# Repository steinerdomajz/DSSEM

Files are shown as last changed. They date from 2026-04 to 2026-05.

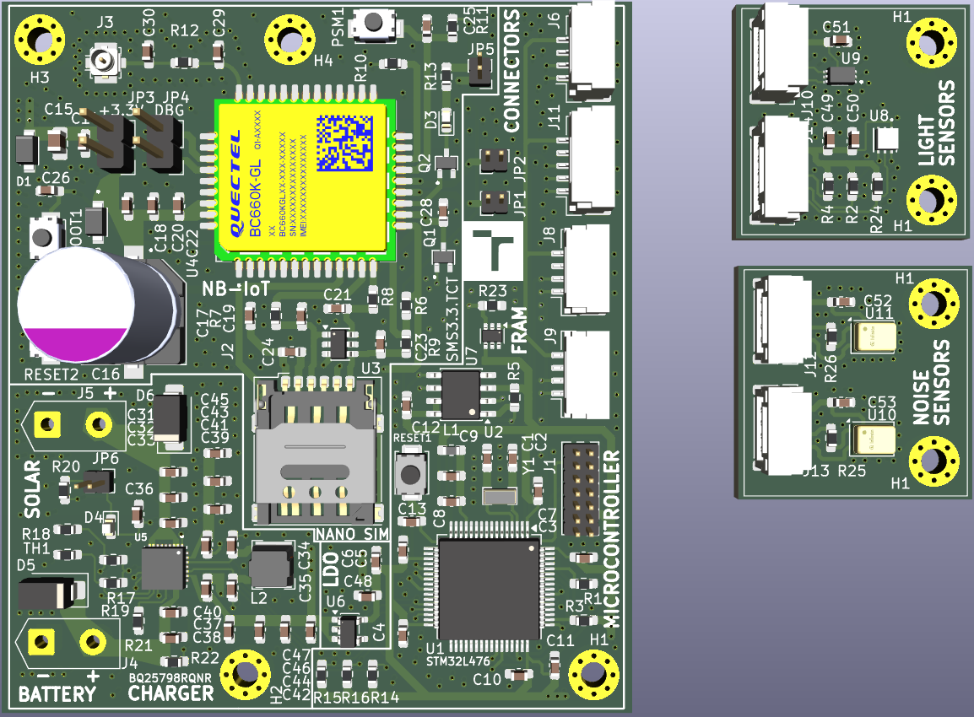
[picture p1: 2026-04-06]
hardware/PCB_front_v02_edit.png

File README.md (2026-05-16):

# System for Environmental Monitoring in Protected Areas
**Master's Thesis Project** | Brno University of Technology (FEKT VUT)

This repository contains a demonstration of my final thesis project: an autonomous IoT system designed for long-term monitoring of acoustic and light pollution in sensitive environments.

Presentation available: DSSEM_presentation.pdf

**Key Features**:
- **Autonomous Operation**: Powered by a solar energy harvesting system.
- **Low-Power Design**: Optimized for long-term deployment in remote areas with minimal maintenance.
- **Connectivity**: Real-time data transmission via NB-IoT.
- **Sensor Precision**: Integrated high-sensitivity sensors for measuring environmental noise and light levels.

**Tech Stack**:
- **Electronics**: Custom PCB designed in KiCad.
- **Firmware**: Developed for MCU to handle sensor data and communication protocols.
- **Mechanical Design**: Protective environmental casing designed in SolidWorks.

--- **Hardware Design & Implementation:** ---

PCB_front_v02_edit

--- **Firmware:** ---






--- **Mechanical Design:** ---





--- **Implementation:** ---

Node-RED Flowchart:



InfluxDB Visualisation:



User Configuration Site (Web Serial API):



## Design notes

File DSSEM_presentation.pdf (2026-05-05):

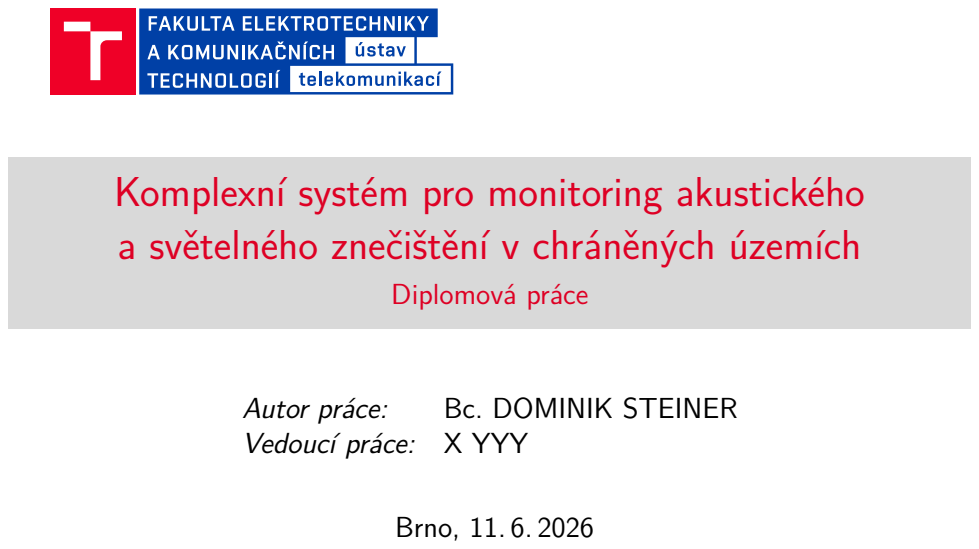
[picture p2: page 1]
Diplomová práce; Autor práce:; Bc. DOMINIK STEINER; Brno, 11. 6. 2026

Komplexní systém pro monitoring akustického
a světelného znečištění v chráněných územích

Vedoucí práce: X YYY

# Cíl práce

# Návrh a realizace systému pro dlouhodobý monitoring akustického a světelného znečištění

# Přenos dat pomocí NB-IoT Energeticky soběstačné řešení založeno na solárním napájení Systém pro bezpečný přenos dat Ukládání dat do databázového systému a následná vizualizace

# Výstupem práce bude funkční prototyp

Bc. Dominik Steiner | Komplexní systém pro monitoring akustického a světelného znečištění v chráněných územích | 1 / 13

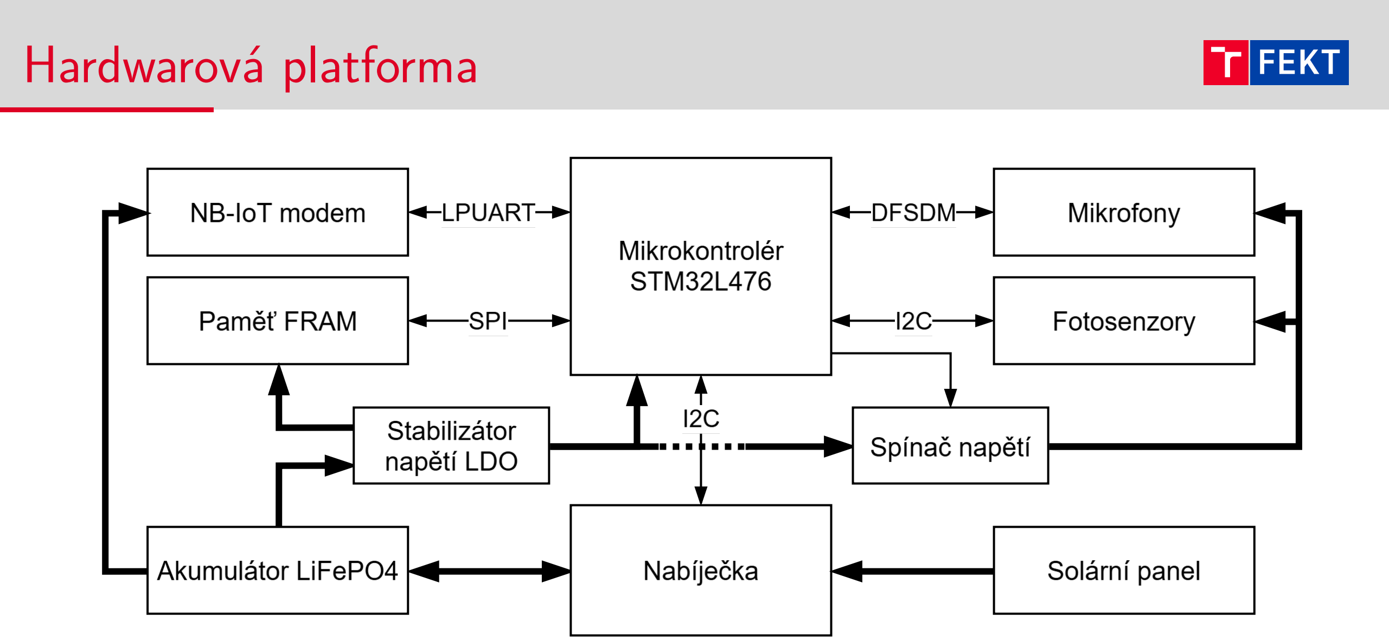
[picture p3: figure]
Hardwarová platforma

# Obr. 1: Blokový diagram HW platformy

Bc. Dominik Steiner | Komplexní systém pro monitoring akustického a světelného znečištění v chráněných územích | 2 / 13

# Hardwarová platforma

# Mikrokontrolér STM32L476

# Ultra-Low-power řada

# NB-IoT modul BC660K-GL

# Nabíječka BQ25798

# LiFePO4 akumulátor

# FRAM MB85RS2MTA

# MEMS mikrofony

# Fotosenzory

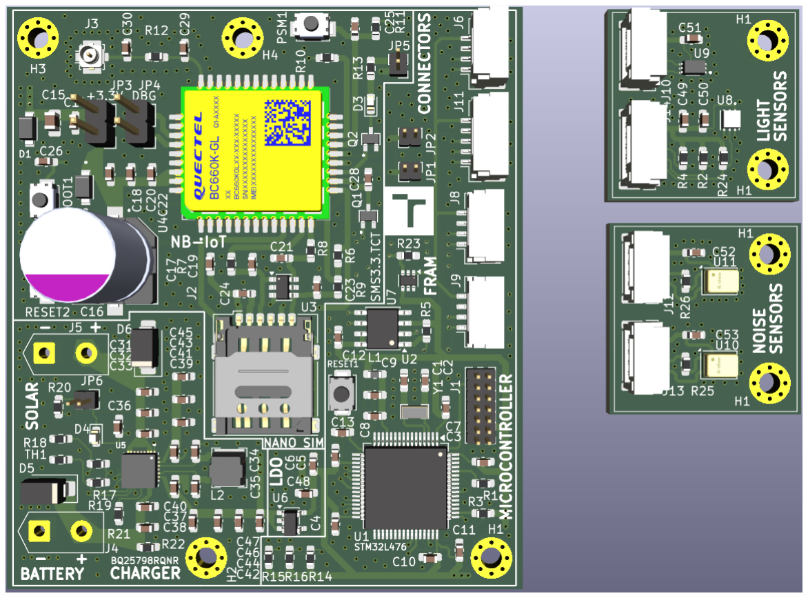
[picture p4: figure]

# Obr. 2: Návrh DPS

Bc. Dominik Steiner | Komplexní systém pro monitoring akustického a světelného znečištění v chráněných územích | 3 / 13

# Firmware

# Senzorové měření

# Měření osvitu Měření hladiny hluku (integrace časového okna)

# Zápis do FRAM

# 16bajtová struktura Až 9375 záznamů Kruhový buffer

# Komunikační blok

# Šifrování AES-128 + CBC

# UDP protokol

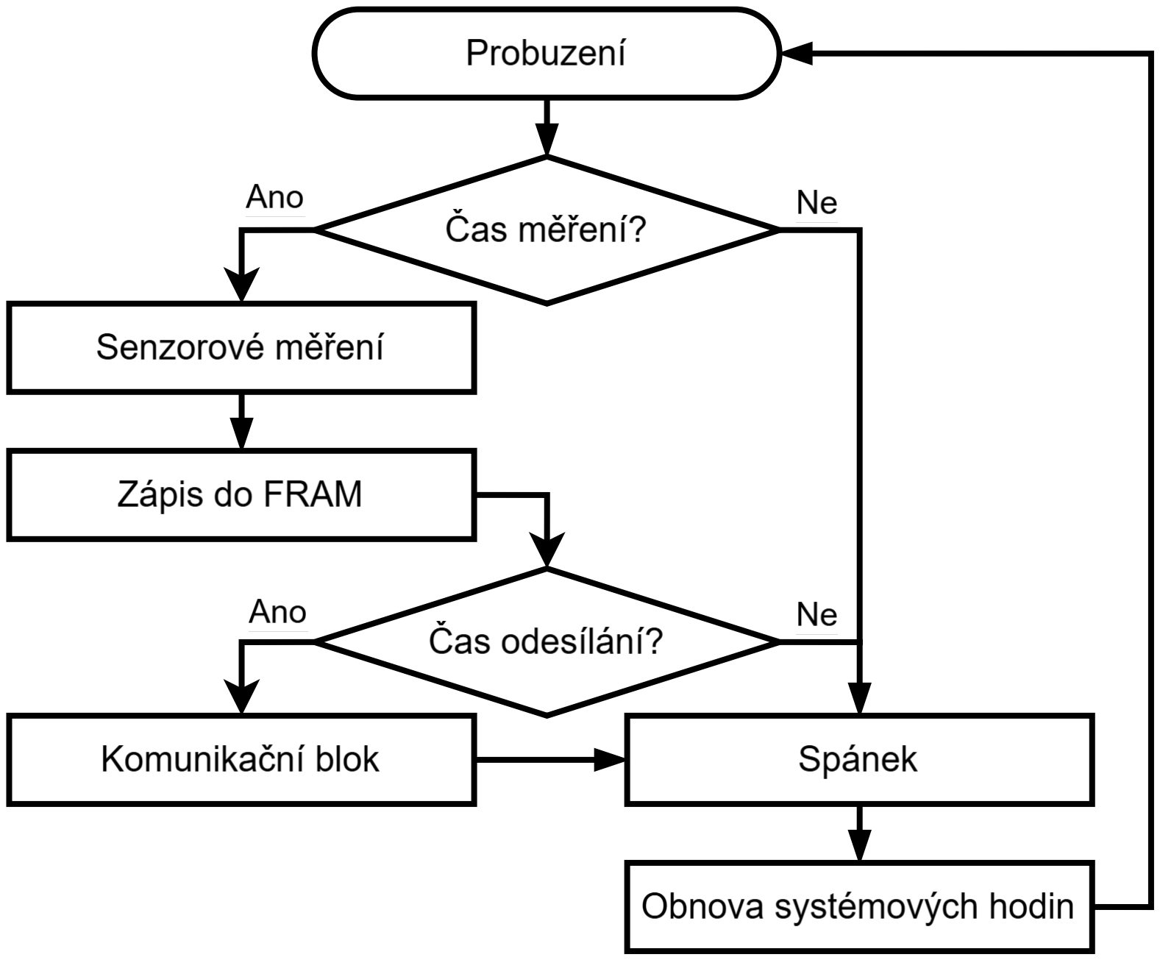
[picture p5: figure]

Spánek | Obr. 3: Zjednodušený diagram hlavního
| cyklu
Bc. Dominik Steiner | Komplexní systém pro monitoring akustického a světelného znečištění v chráněných územích | 4 / 13

# Server

# Stamp Check: Kontrola identifikační značky

# Decryption: Dešifrování dat

# Time Shift: Převod lokálního času na UTC

# Format for InfluxDB: Formátování dat v souladu s InfluxDB

# Obr. 4: Flow chart Node-RED

Bc. Dominik Steiner | Komplexní systém pro monitoring akustického a světelného znečištění v chráněných územích | 5 / 13

# Energetická náročnost zařízení

# Spánek

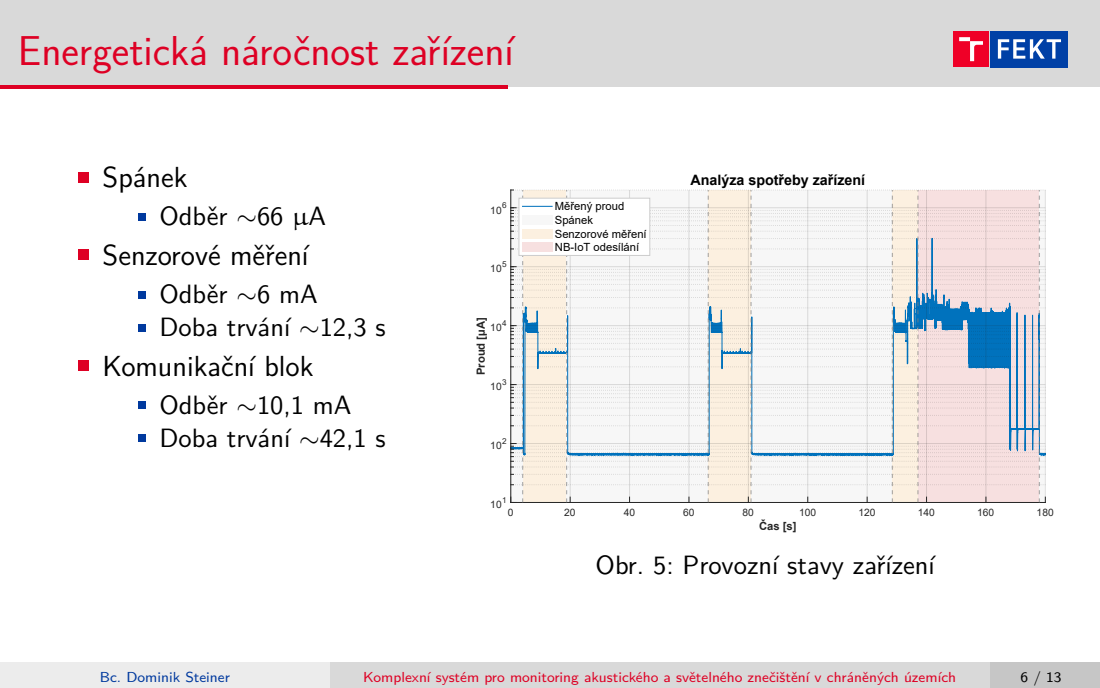
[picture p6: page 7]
Odběr ∼66 µA; Senzorové měření; Odběr ∼6 mA Doba trvání ∼12,3 s; Komunikační blok; Odběr ∼10,1 mA Doba trvání ∼42,1 s; Čas [s]; Proud [µA]; Bc. Dominik Steiner; Komplexní systém pro monitoring akustického a světelného znečištění v chráněných územích

Analýza spotřeby zařízení

Měřený proud
Spánek
Senzorové měření
NB-IoT odesílání

Obr. 5: Provozní stavy zařízení

# Energetická náročnost zařízení

# Připojování do sítě

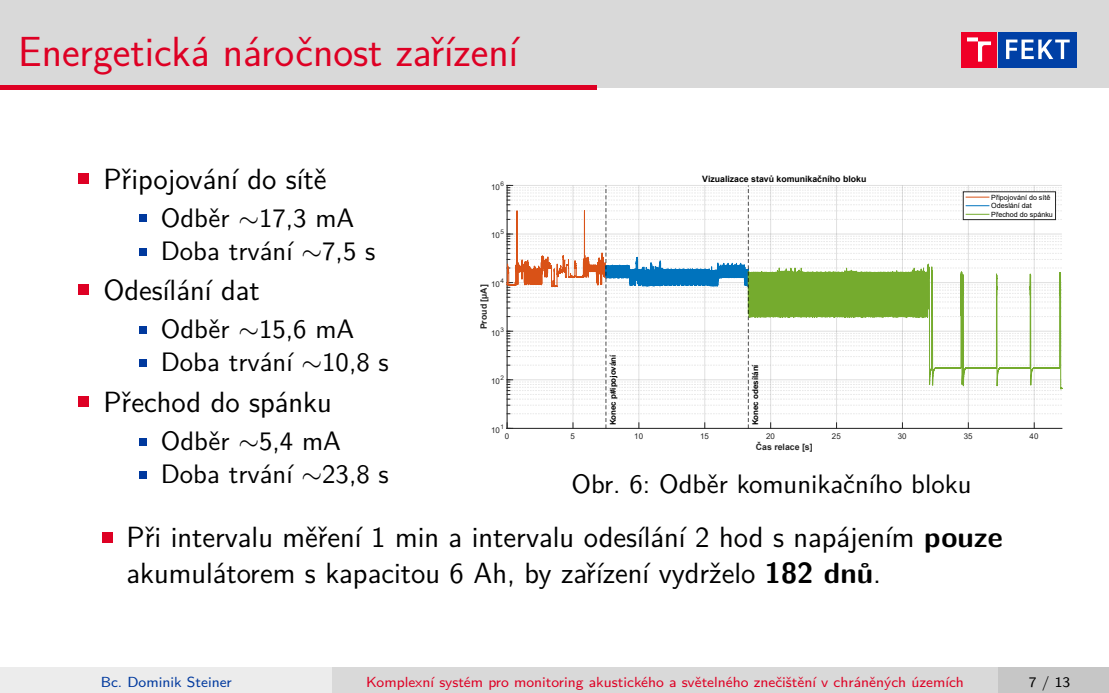
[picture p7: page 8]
Čas relace [s]; Proud [µA]; Konec p#ipojování; Konec odesílání; Bc. Dominik Steiner; Komplexní systém pro monitoring akustického a světelného znečištění v chráněných územích

Vizualizace stavů komunikačního bloku

Připojování do sítě
Odeslání dat
Přechod do spánku

Odběr ∼17,3 mA
Doba trvání ∼7,5 s
Odesílání dat
Odběr ∼15,6 mA
Doba trvání ∼10,8 s
Odběr ∼5,4 mA
Doba trvání ∼23,8 s

Obr. 6: Odběr komunikačního bloku

Při intervalu měření 1 min a intervalu odesílání 2 hod s napájením pouze
akumulátorem s kapacitou 6 Ah, by zařízení vydrželo 182 dnů.

# Mechanické pouzdro

# Základový modul + senzorové moduly

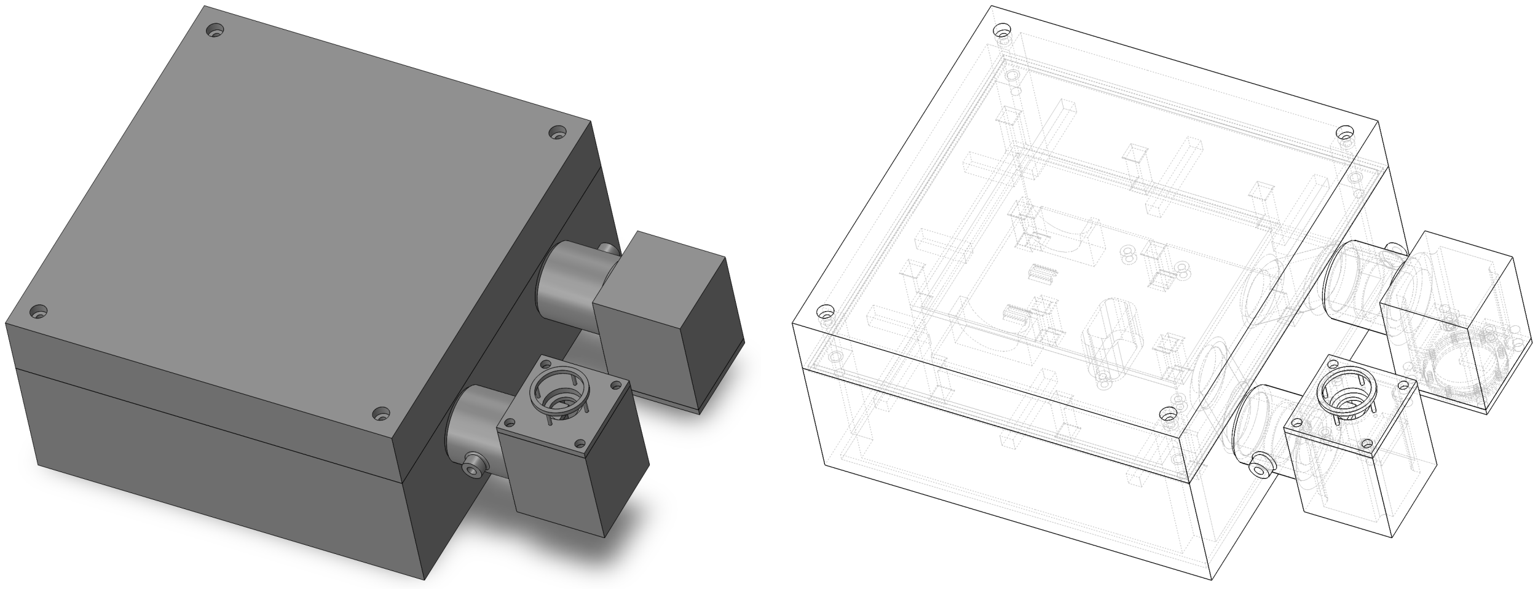
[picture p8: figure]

# Obr. 7: Model mechanického pouzdra zařízení

Bc. Dominik Steiner | Komplexní systém pro monitoring akustického a světelného znečištění v chráněných územích | 8 / 13

# Základový modul

# Komora pro akumulátor a DPS Izolace pomocí pěnového polyuretanu (PUR)

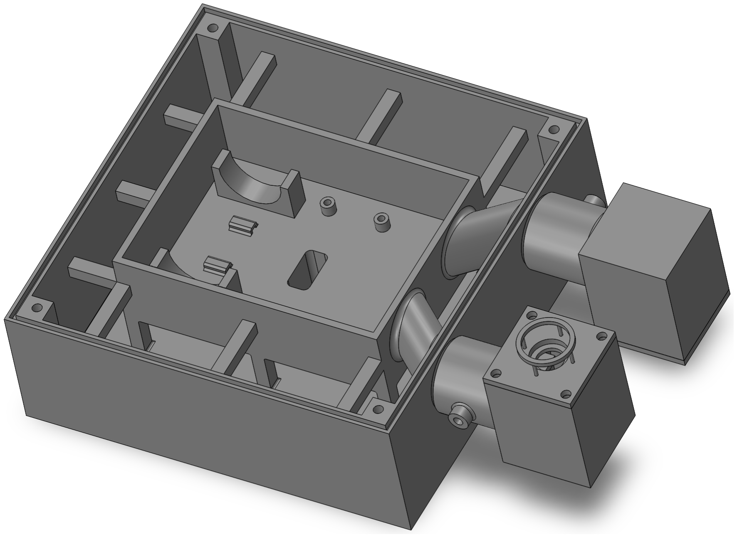
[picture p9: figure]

# Obr. 8: Model základového modulu

Bc. Dominik Steiner | Komplexní systém pro monitoring akustického a světelného znečištění v chráněných územích | 9 / 13

# Senzorové moduly

# Otáčivé moduly pro fotosentory

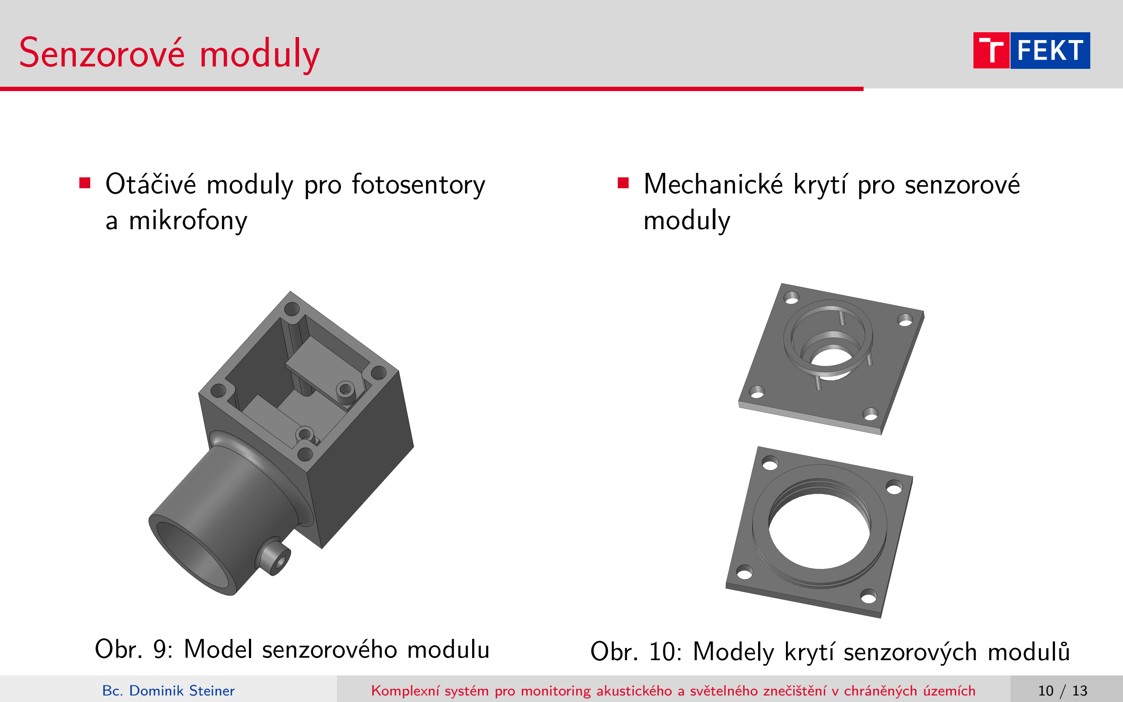
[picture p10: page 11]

# a mikrofony

# Obr. 9: Model senzorového modulu

# Mechanické krytí pro senzorové moduly

# Obr. 10: Modely krytí senzorových modulů

Bc. Dominik Steiner | Komplexní systém pro monitoring akustického a světelného znečištění v chráněných územích | 10 / 13

# Program DSSEM User Configuration

# Jednoduchá uživatelské aplikace pro nastavení:

# Serveru Identifikační značky Intervalu měření a odesílání

# Připojení se zařízením skrze Web Serial API (USB-TTL + UART)

# Výpočet odhadované životnosti zařízení

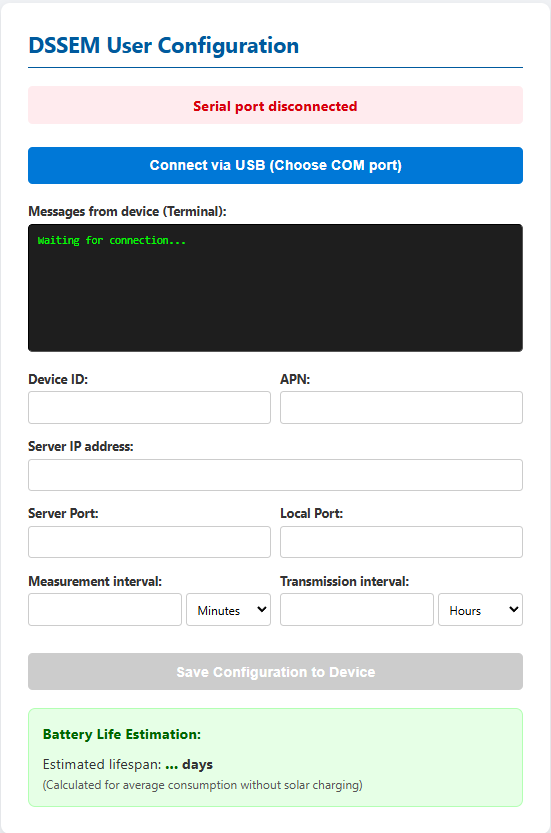
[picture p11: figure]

# Obr. 11: Program User Configuration

Bc. Dominik Steiner | Komplexní systém pro monitoring akustického a světelného znečištění v chráněných územích | 11 / 13

# Závěr

# Realizace návrhu HW platformy

# Měření osvitu a akustického hluku Přenos dat pomocí NB-IoT

# Realizace FW zařízení

# Implementováno šifrování a kruhový buffer pro ukládání dat Ověřena funkční komunikace se vzdáleným serverem Dosažení odběru 66 µA ve spánku

# Mechanické pouzdro

# Vytvořeny modely mechanického pouzdra

# Potřebné kroky pro finalizaci projektu

# 1. Mechanické pouzdro a textová část DP: 2. Program DSSEM User Configuration

Bc. Dominik Steiner | Komplexní systém pro monitoring akustického a světelného znečištění v chráněných územích | 12 / 13

# Děkuji za pozornost!

Bc. Dominik Steiner | Komplexní systém pro monitoring akustického a světelného znečištění v chráněných územích | 13 / 13

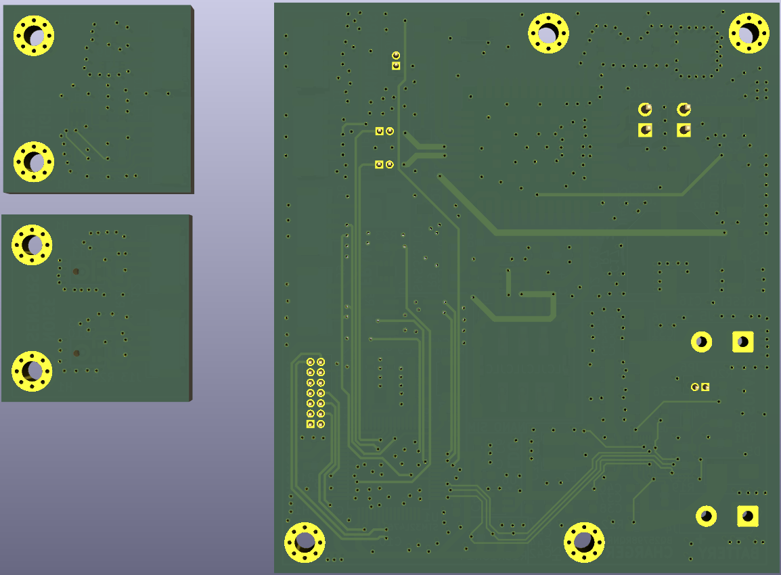
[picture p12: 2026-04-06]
hardware/PCB_back_v02_edit.png

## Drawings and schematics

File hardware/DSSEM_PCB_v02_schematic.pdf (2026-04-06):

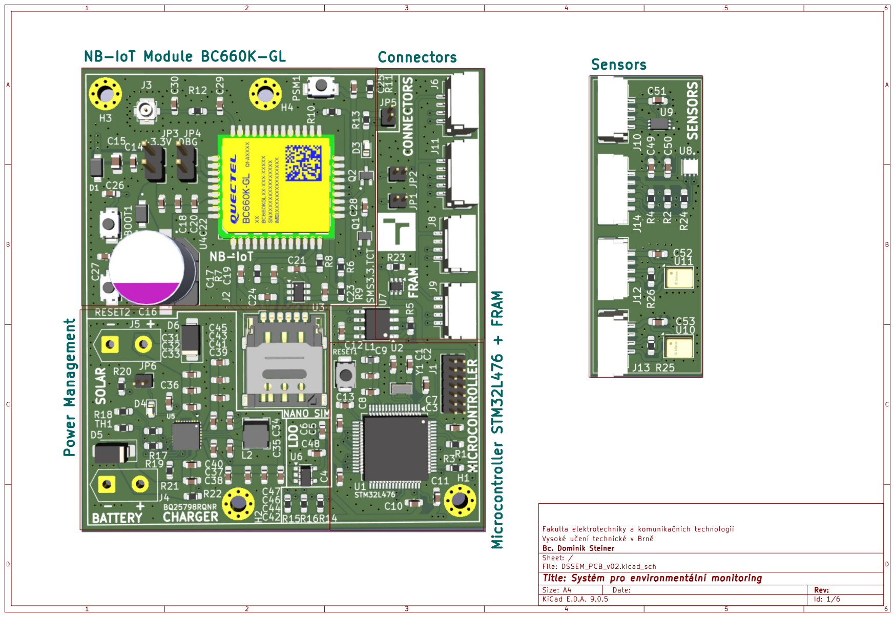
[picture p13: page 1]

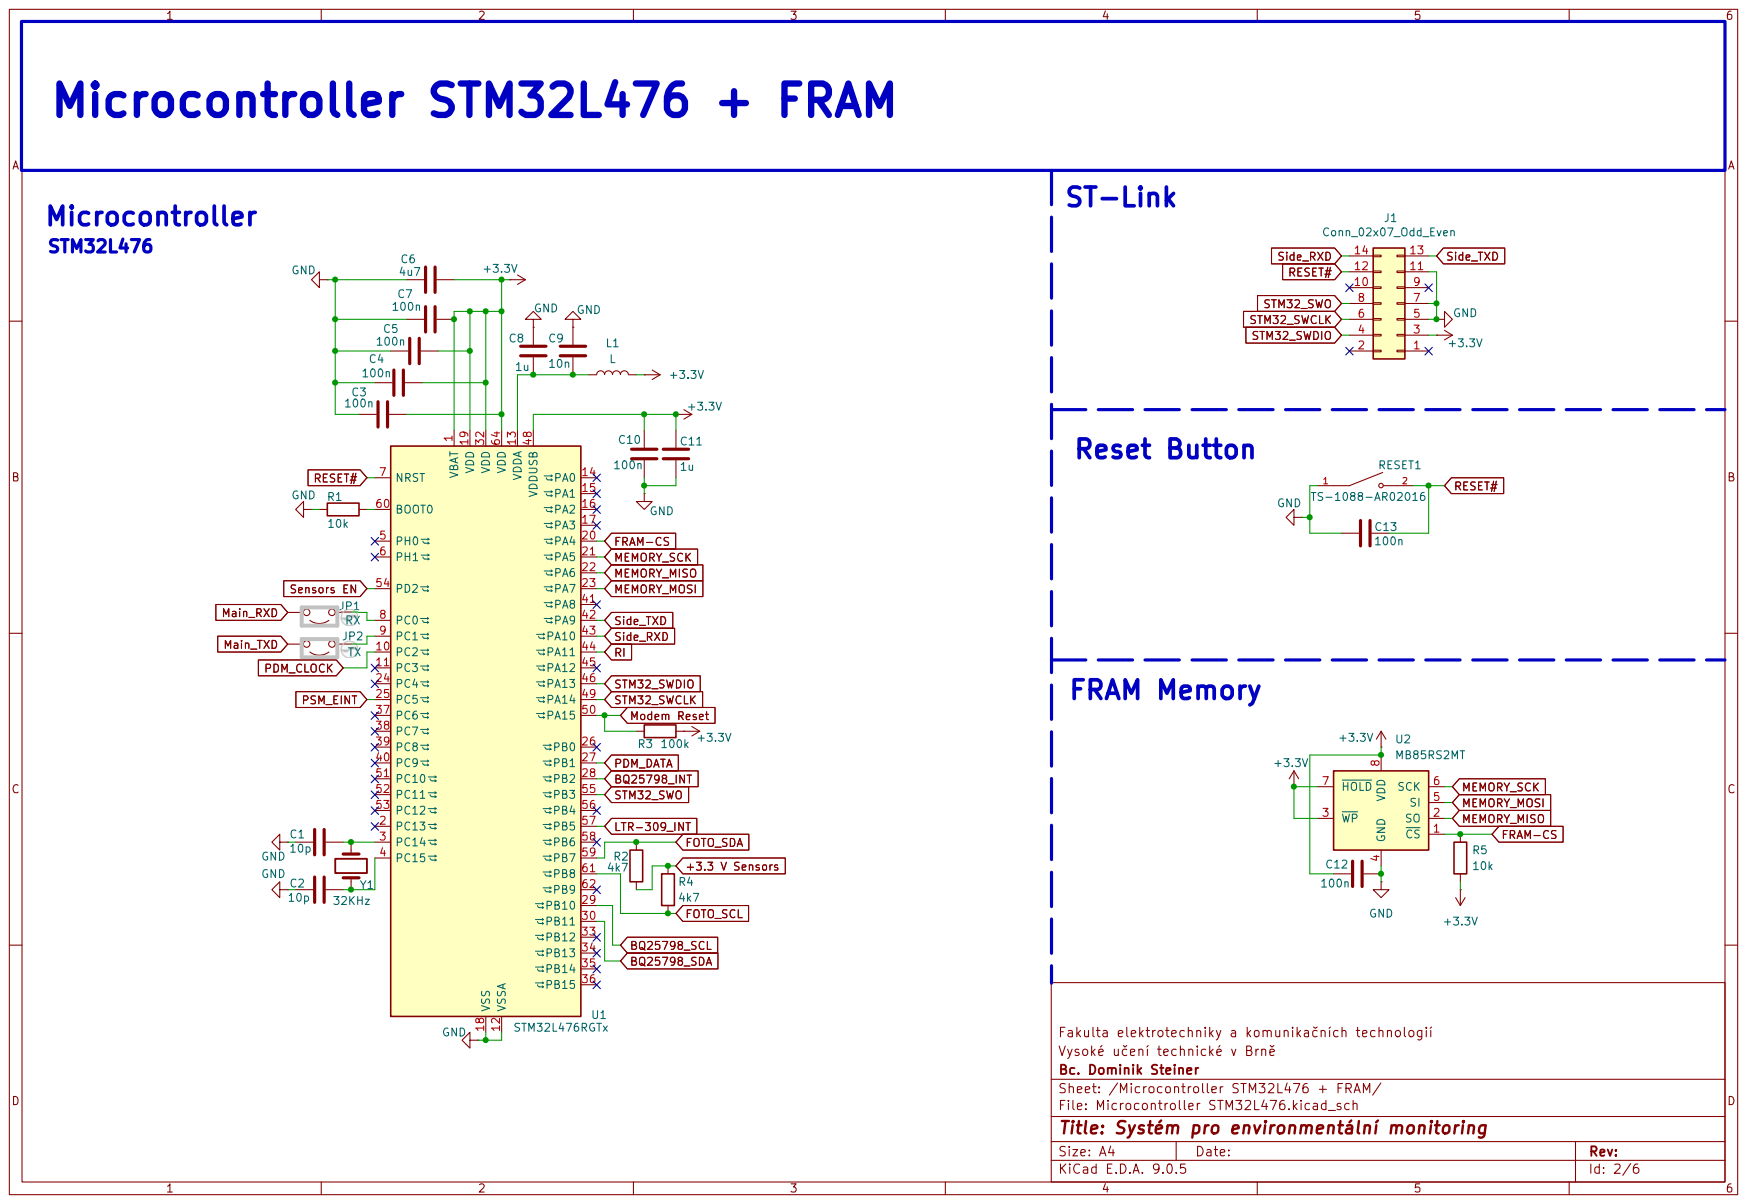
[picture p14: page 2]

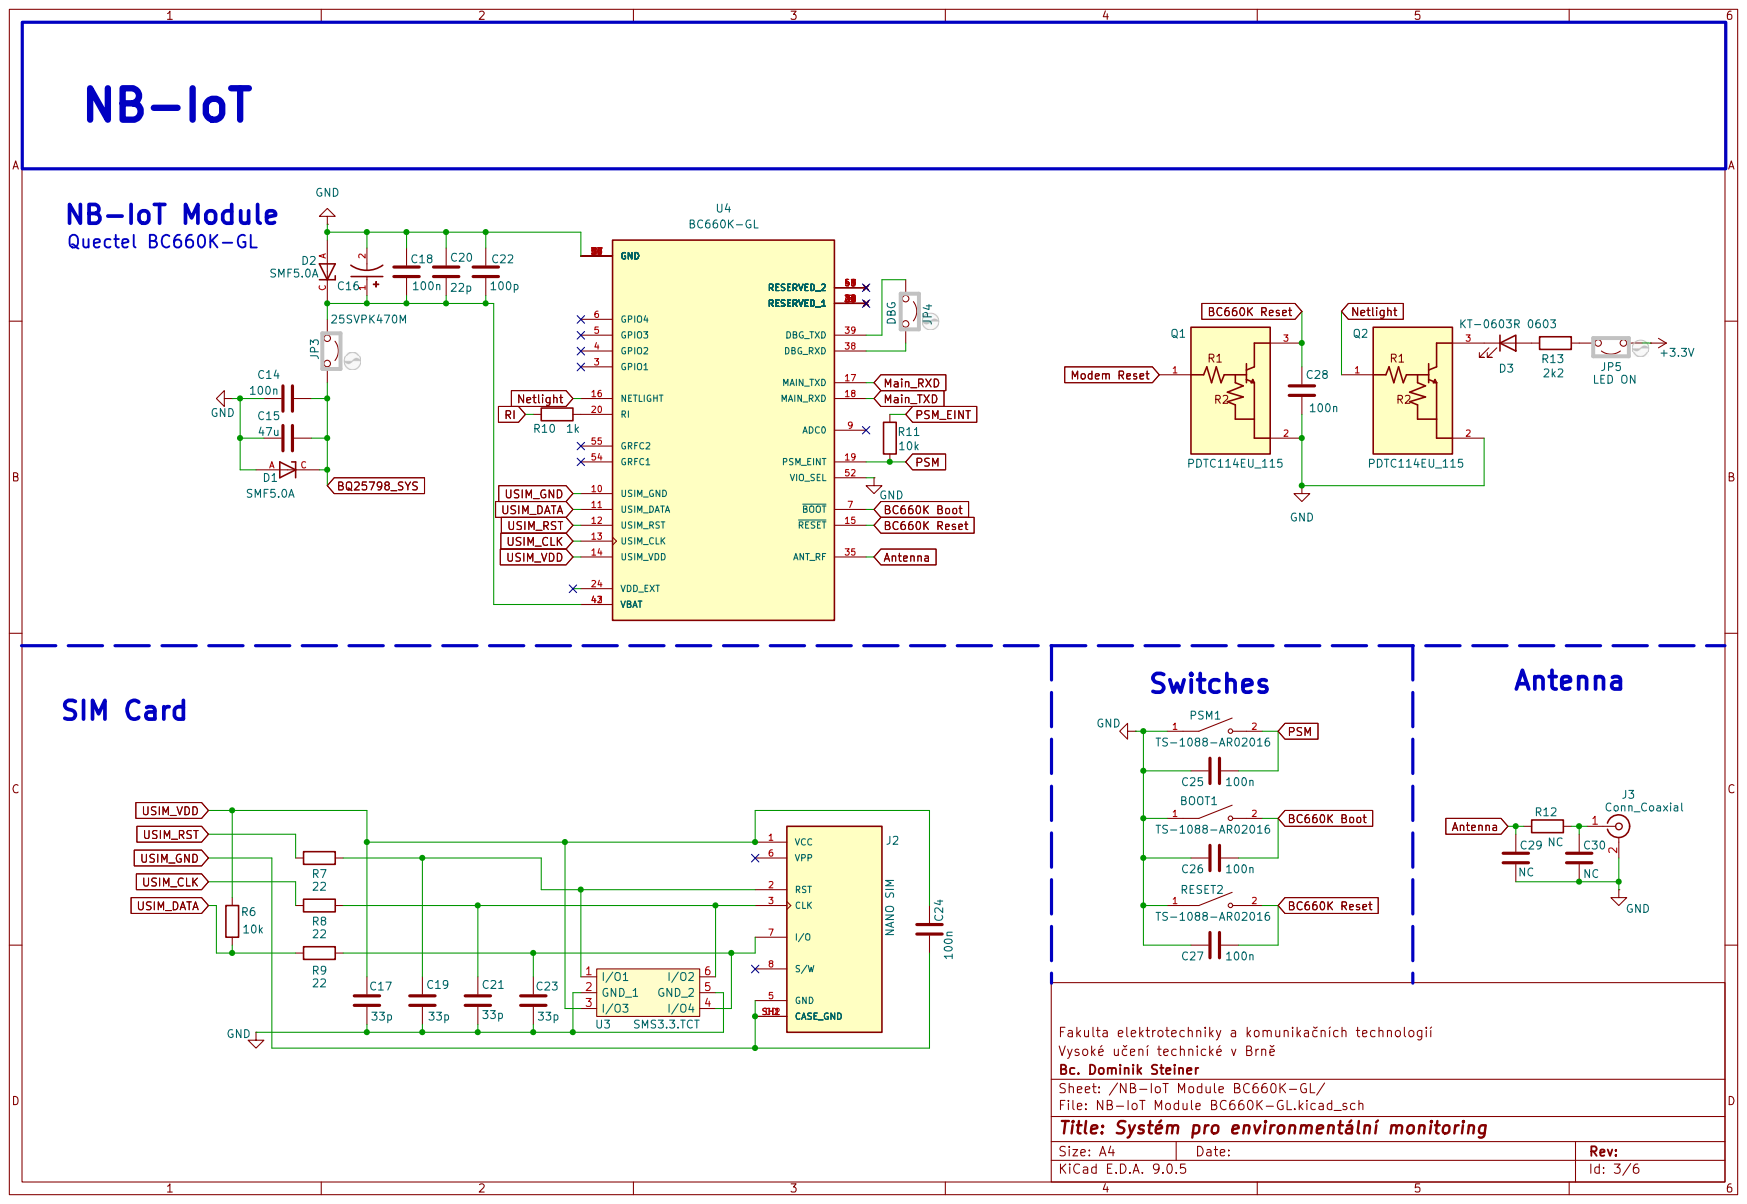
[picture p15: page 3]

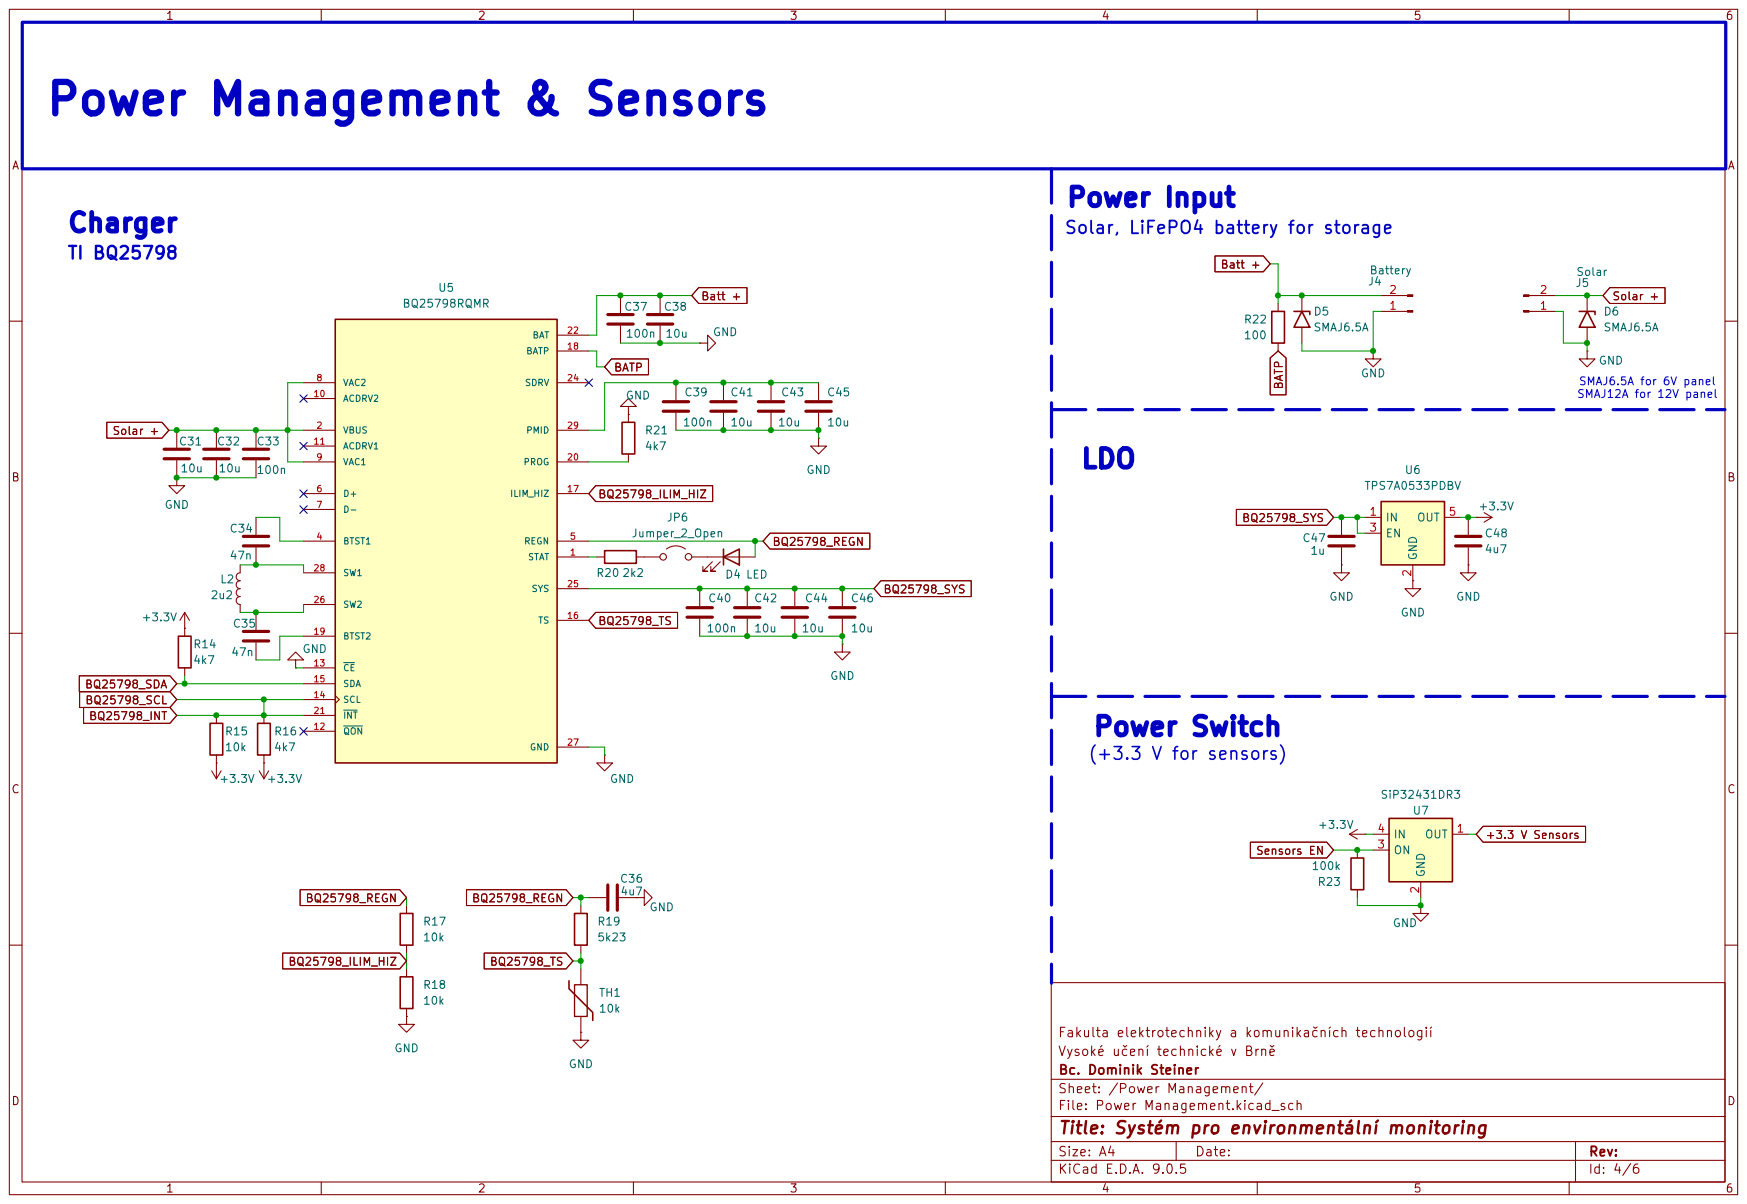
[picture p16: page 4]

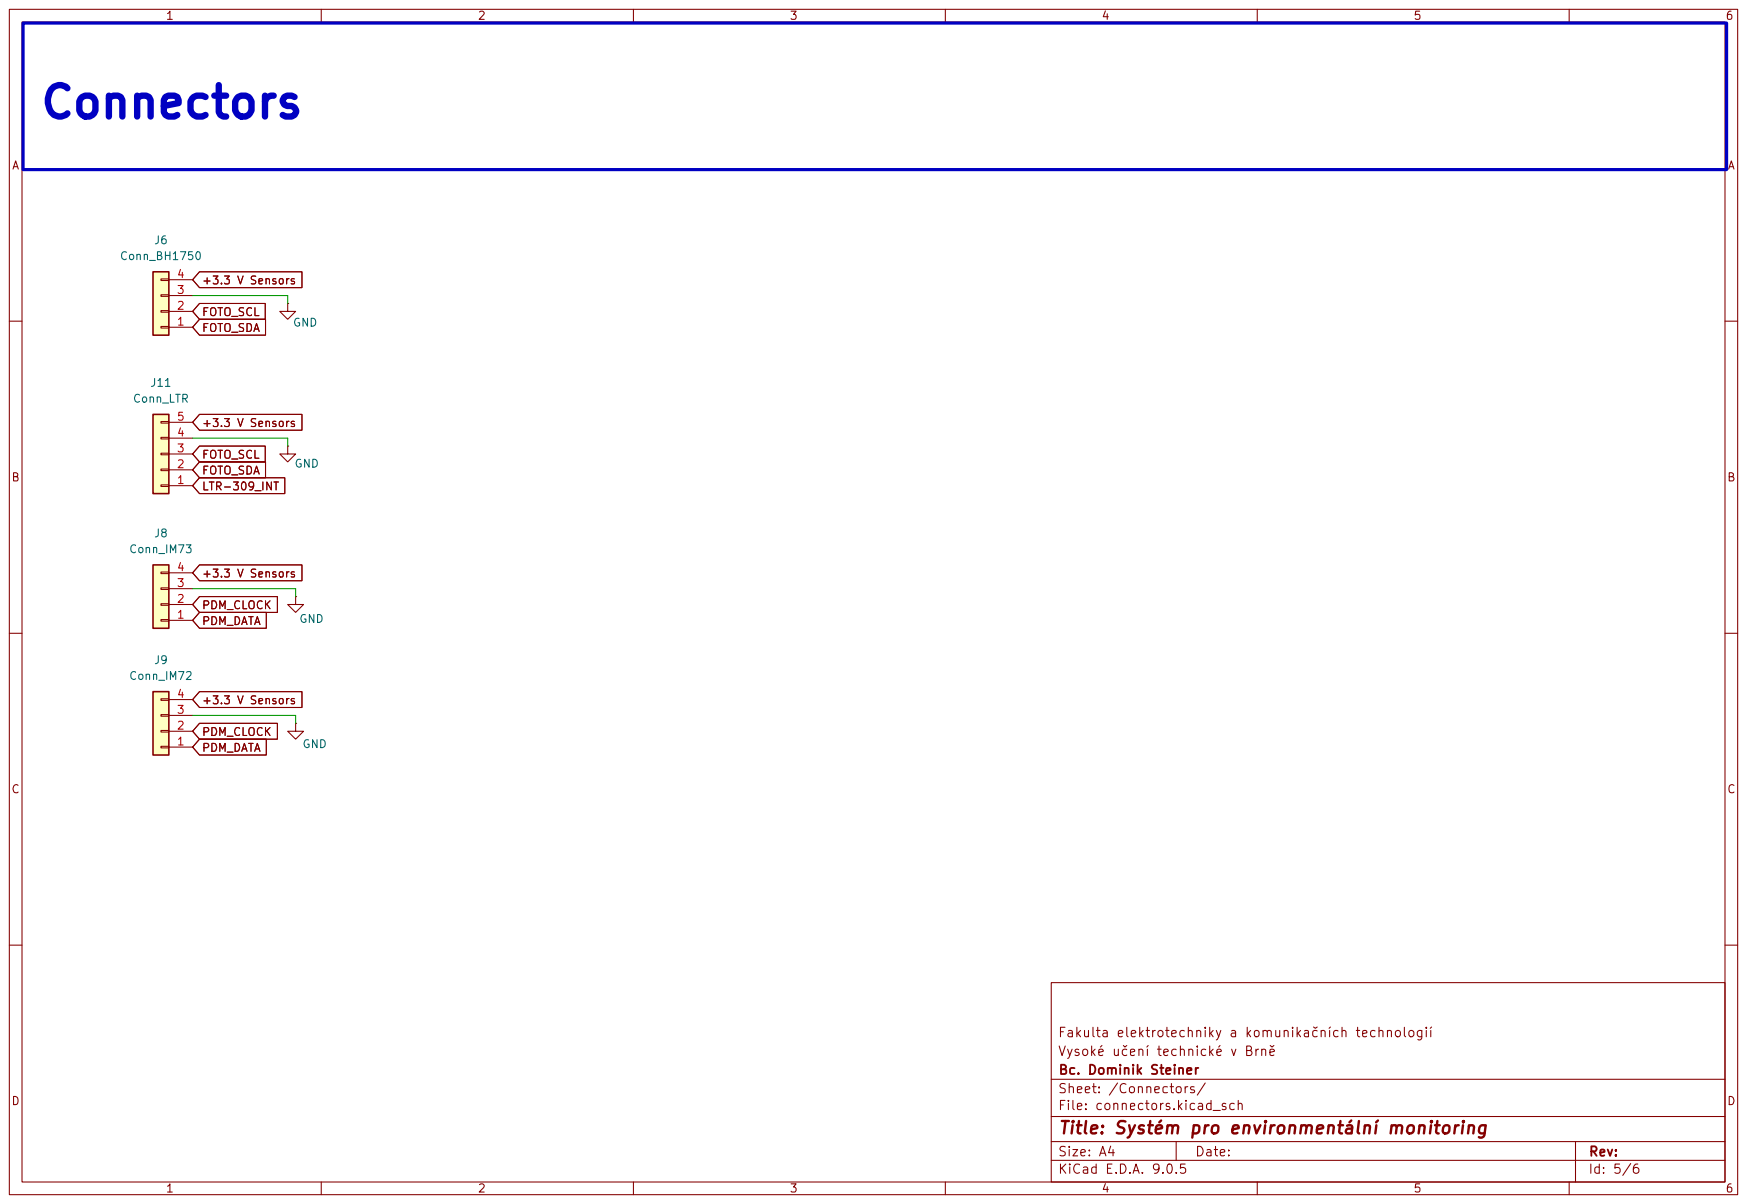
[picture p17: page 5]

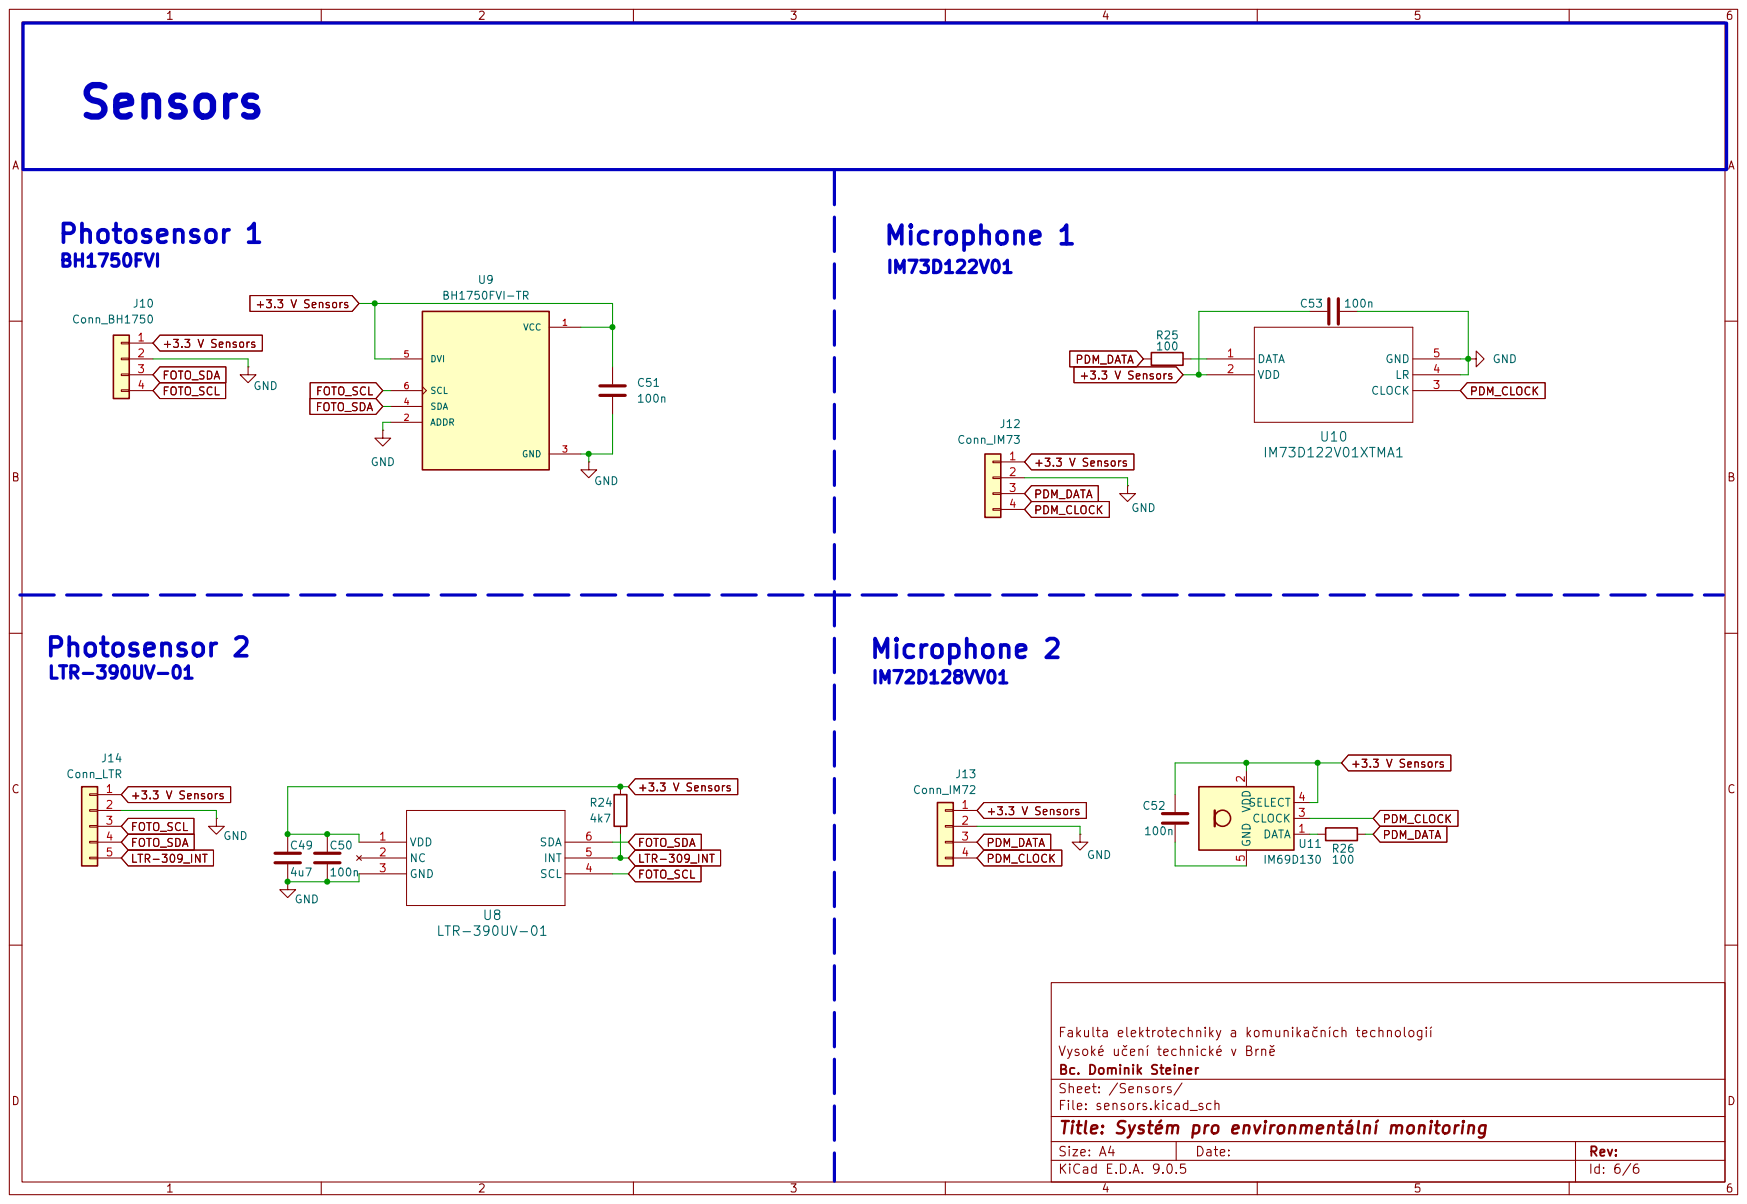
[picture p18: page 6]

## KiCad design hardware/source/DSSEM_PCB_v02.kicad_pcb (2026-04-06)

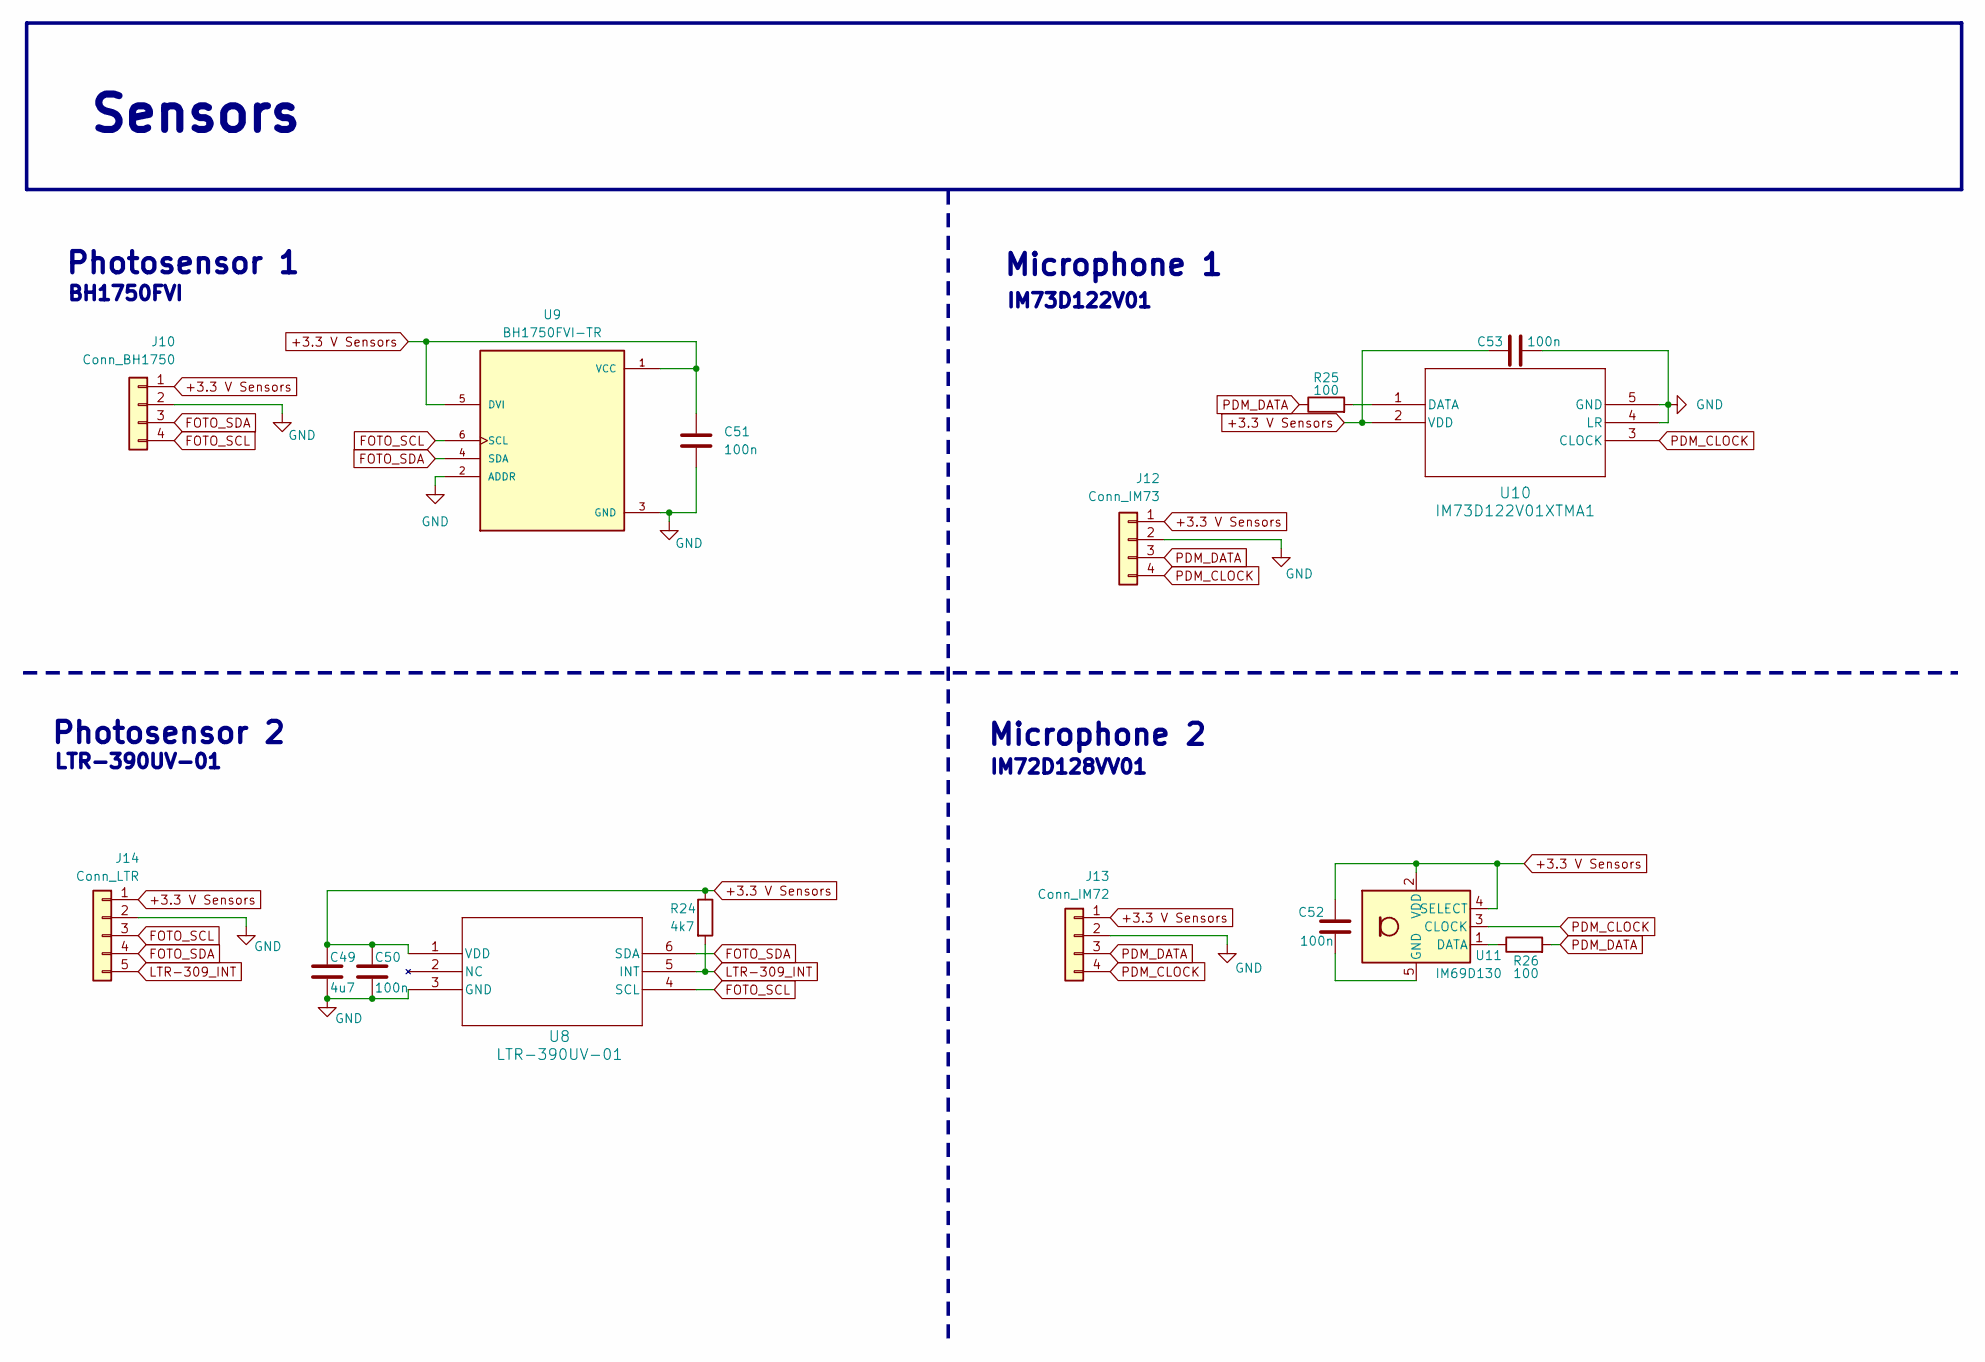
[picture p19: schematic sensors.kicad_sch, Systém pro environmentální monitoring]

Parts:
C49: 4u7; C_0603_1608Metric_Pad1.08x0.95mm_HandSolder
C50, C51, C52, C53: 100n; C_0603_1608Metric_Pad1.08x0.95mm_HandSolder
J10: Conn_BH1750; JST_GH_SM04B-GHS-TB_1x04-1MP_P1.25mm_Horizontal
J12: Conn_IM73; JST_GH_SM04B-GHS-TB_1x04-1MP_P1.25mm_Horizontal
J13: Conn_IM72; JST_GH_SM04B-GHS-TB_1x04-1MP_P1.25mm_Horizontal
J14: Conn_LTR; JST_GH_SM05B-GHS-TB_1x05-1MP_P1.25mm_Horizontal
R24: 4k7; R_0603_1608Metric_Pad0.98x0.95mm_HandSolder
R25, R26: 100; R_0603_1608Metric_Pad0.98x0.95mm_HandSolder
U8: LTR-390UV-01; SMD6_LTR-390UV-01_LTO
U9: BH1750FVI-TR; XDCR_BH1750FVI-TR; PARTREV D
U10: IM73D122V01XTMA1; Infineon_PG-LLGA-5-2
U11: IM69D130; Infineon_PG-LLGA-5-1

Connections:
+3.3 V Sensors: C49.1, C50.1, C51.1, C52.1, C53.1, J10.1, J12.1, J13.1, J14.1, R24.1, U8.1 (VDD), U9.1 (VCC), U9.5 (DVI), U10.2 (VDD), U11.2 (VDD), U11.4 (SELECT); also elsewhere on the board
FOTO_SCL: J10.4, J14.3, U8.4 (SCL), U9.6 (SCL); also elsewhere on the board
FOTO_SDA: J10.3, J14.4, U8.6 (SDA), U9.4 (SDA); also elsewhere on the board
GND: C49.2, C50.2, C51.2, C53.2, J10.2, J12.2, J13.2, J14.2, U8.3 (GND), U9.2 (ADDR), U9.3 (GND), U10.4 (LR), U10.5 (GND); also elsewhere on the board
LTR-309_INT: J14.5, R24.2, U8.5 (INT); also elsewhere on the board
unnamed: R25.2, U10.1 (DATA)
unnamed: R26.1, U11.1 (DATA)
unnamed: C52.2, U11.5 (GND)
PDM_CLOCK: J12.4, J13.4, U10.3 (CLOCK), U11.3 (CLOCK); also elsewhere on the board
PDM_DATA: J12.3, J13.3, R25.1, R26.2; also elsewhere on the board

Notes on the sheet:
Microphone 2
BH1750FVI
Photosensor 1
LTR-390UV-01
IM73D122V01
IM72D128VV01
Photosensor 2
Sensors
Microphone 1

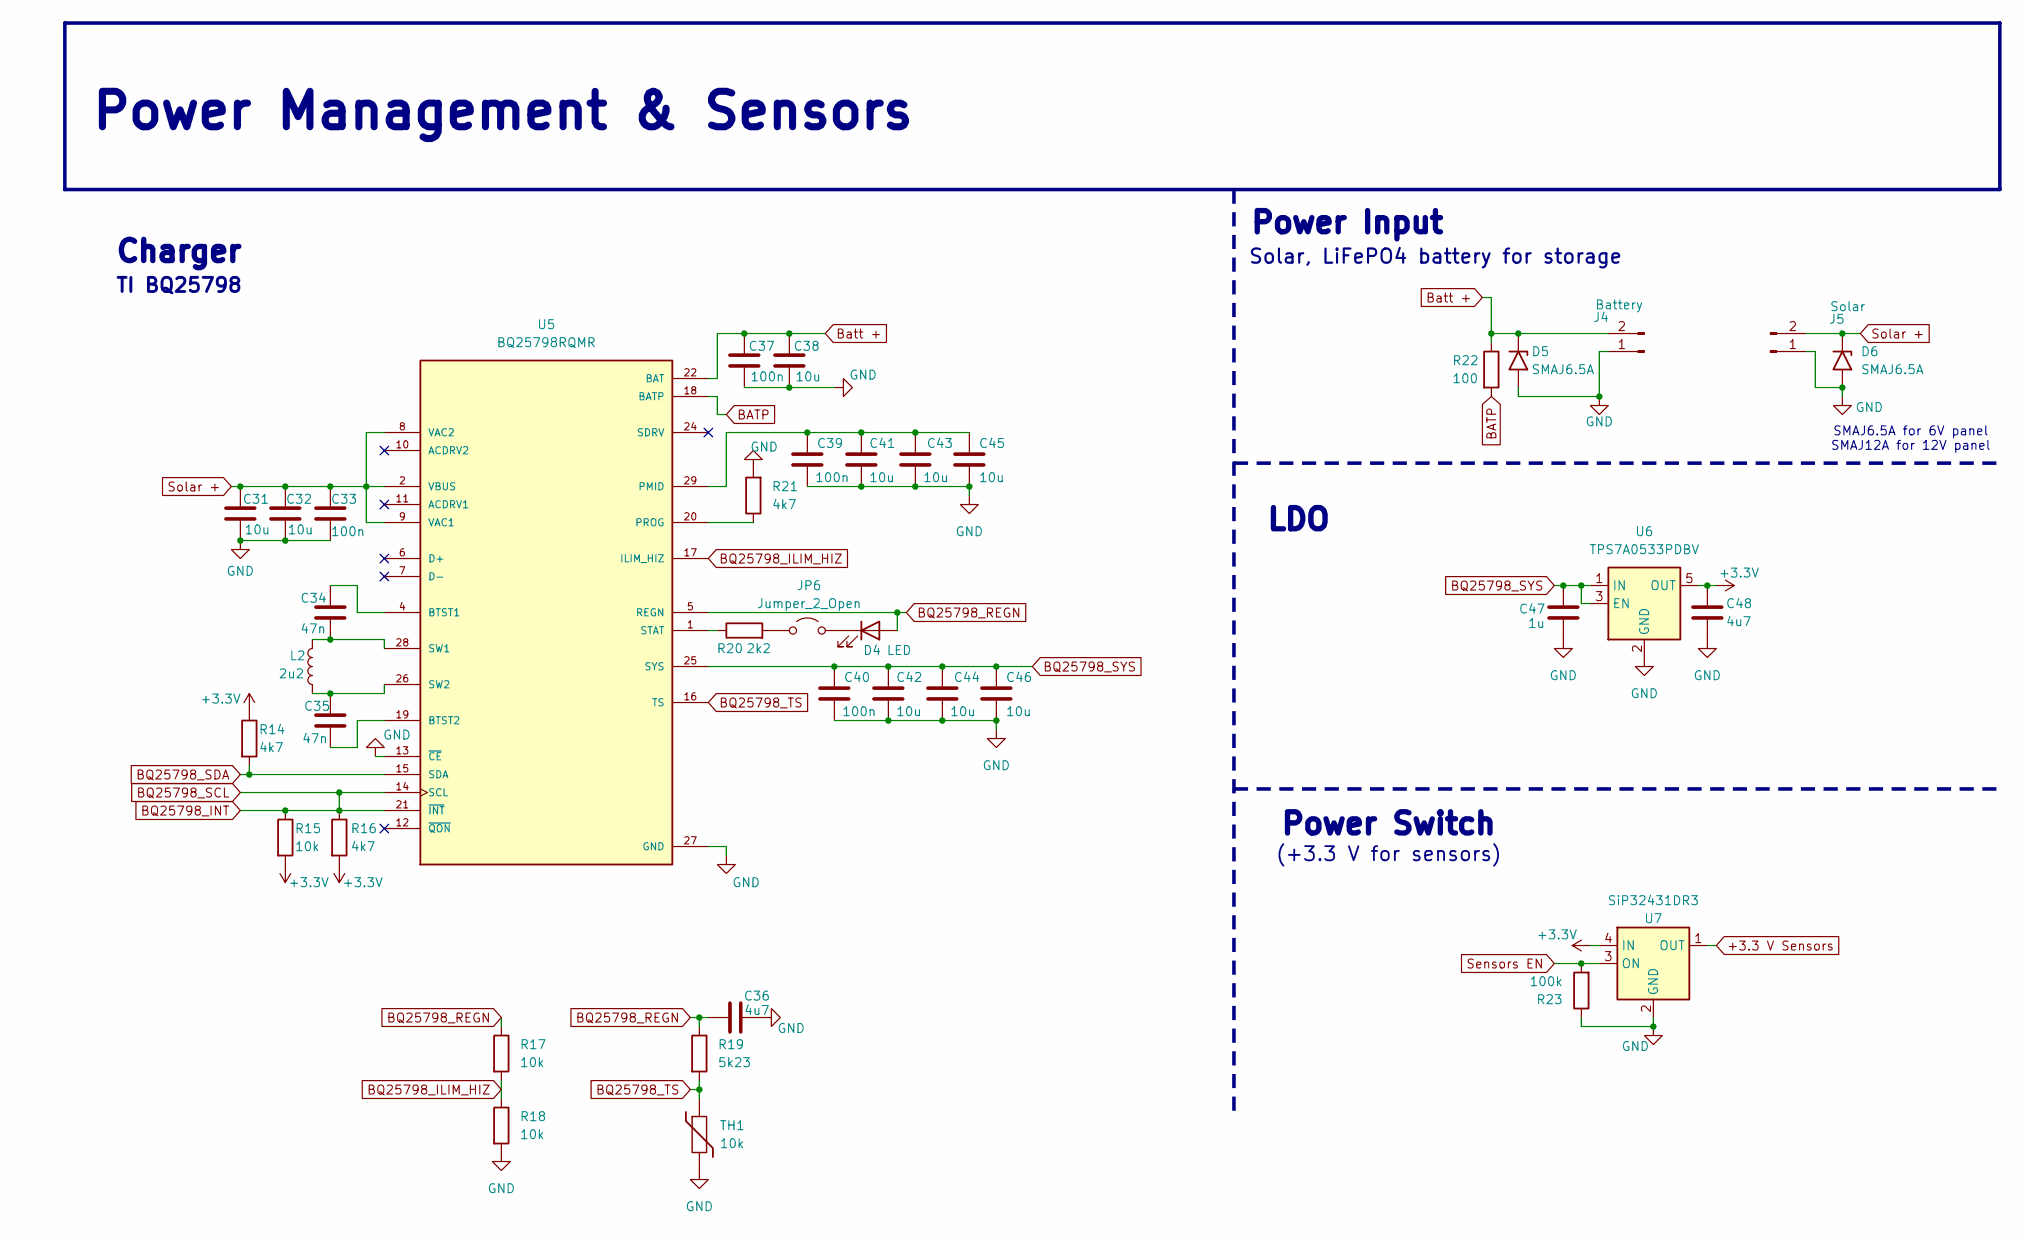
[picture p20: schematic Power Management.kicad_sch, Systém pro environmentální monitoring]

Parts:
C31, C32, C38, C41, C42, C43, C44, C45, C46: 10u; C_0603_1608Metric_Pad1.08x0.95mm_HandSolder
C33, C37, C39, C40: 100n; C_0603_1608Metric_Pad1.08x0.95mm_HandSolder
C34, C35: 47n; C_0603_1608Metric_Pad1.08x0.95mm_HandSolder
C36, C48: 4u7; C_0603_1608Metric_Pad1.08x0.95mm_HandSolder
C47: 1u; C_0603_1608Metric_Pad1.08x0.95mm_HandSolder
D4: LED; LED_0603_1608Metric
D5, D6: SMAJ6.5A; D_SMA
J4: Battery; TerminalBlock_Phoenix_MKDS-1,5-2-5.08_1x02_P5.08mm_Horizont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
J5: Solar; TerminalBlock_Phoenix_MKDS-1,5-2-5.08_1x02_P5.08mm_Horizont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
JP6: Jumper_2_Open; PinHeader_1x02_P1.27mm_Vertical
L2: 2u2; L_Bourns-SRN4018
R14, R16, R21: 4k7; R_0603_1608Metric_Pad0.98x0.95mm_HandSolder
R15, R17, R18: 10k; R_0603_1608Metric_Pad0.98x0.95mm_HandSolder
R19: 5k23; R_0603_1608Metric_Pad0.98x0.95mm_HandSolder
R20: 2k2; R_0603_1608Metric_Pad0.98x0.95mm_HandSolder
R22: 100; R_0603_1608Metric_Pad0.98x0.95mm_HandSolder
R23: 100k; R_0603_1608Metric_Pad0.98x0.95mm_HandSolder
TH1: 10k; R_0603_1608Metric_Pad0.98x0.95mm_HandSolder
U5: BQ25798RQMR; IC_BQ25798RQMR; PARTREV B
U6: TPS7A0533PDBV; SOT-23-5
U7: SiP32431DR3; SOT-363_SC-70-6

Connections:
+3.3 V Sensors: U7.1 (OUT); also elsewhere on the board
+3.3V: C48.1, R14.1, R15.2, R16.2, U6.5 (OUT), U7.4 (IN); also elsewhere on the board
BATP: R22.2, U5.18 (BATP)
BQ25798_ILIM_HIZ: R17.2, R18.1, U5.17 (ILIM_HIZ)
BQ25798_INT: R15.1, R16.1, U5.14 (SCL), U5.21 (~INT); also elsewhere on the board
BQ25798_REGN: C36.1, D4.2 (A), R17.1, R19.1, U5.5 (REGN)
BQ25798_SDA: R14.2, U5.15 (SDA); also elsewhere on the board
BQ25798_SYS: C40.1, C42.1, C44.1, C46.1, C47.1, U5.25 (SYS), U6.1 (IN), U6.3 (EN); also elsewhere on the board
BQ25798_TS: R19.2, TH1.1, U5.16 (TS)
Batt +: C37.1, C38.1, D5.1 (A1), J4.2, R22.1, U5.22 (BAT), U5.23 (BAT)
GND: C31.2, C32.2, C33.2, C36.2, C37.2, C38.2, C39.2, C40.2, C41.2, C42.2, C43.2, C44.2, C45.2, C46.2, C47.2, C48.2, D5.2 (A2), D6.2 (A2), J4.1, J5.1, R18.2, R21.2, R23.1, TH1.2, U5.13 (~CE), U5.27 (GND), U6.2 (GND), U7.2 (GND), U7.5 (GND); also elsewhere on the board
unnamed: D4.1 (K), JP6.2 (B)
unnamed: JP6.1 (A), R20.2
unnamed: C34.1, U5.4 (BTST1)
unnamed: C35.2, U5.19 (BTST2)
unnamed: C39.1, C41.1, C43.1, C45.1, U5.29 (PMID)
unnamed: R21.1, U5.20 (PROG)
unnamed: R20.1, U5.1 (STAT)
unnamed: C34.2, L2.2, U5.28 (SW1)
unnamed: C35.1, L2.1, U5.26 (SW2)
Sensors EN: R23.2, U7.3 (ON); also elsewhere on the board
Solar +: C31.1, C32.1, C33.1, D6.1 (A1), J5.2, U5.2 (VBUS), U5.3 (VBUS), U5.8 (VAC2), U5.9 (VAC1)

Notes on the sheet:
LDO
TI BQ25798
Solar, LiFePO4 battery for storage
(+3.3 V for sensors)
Power Management & Sensors
Power Input
Power Switch
Charger
SMAJ6.5A for 6V panel SMAJ12A for 12V panel

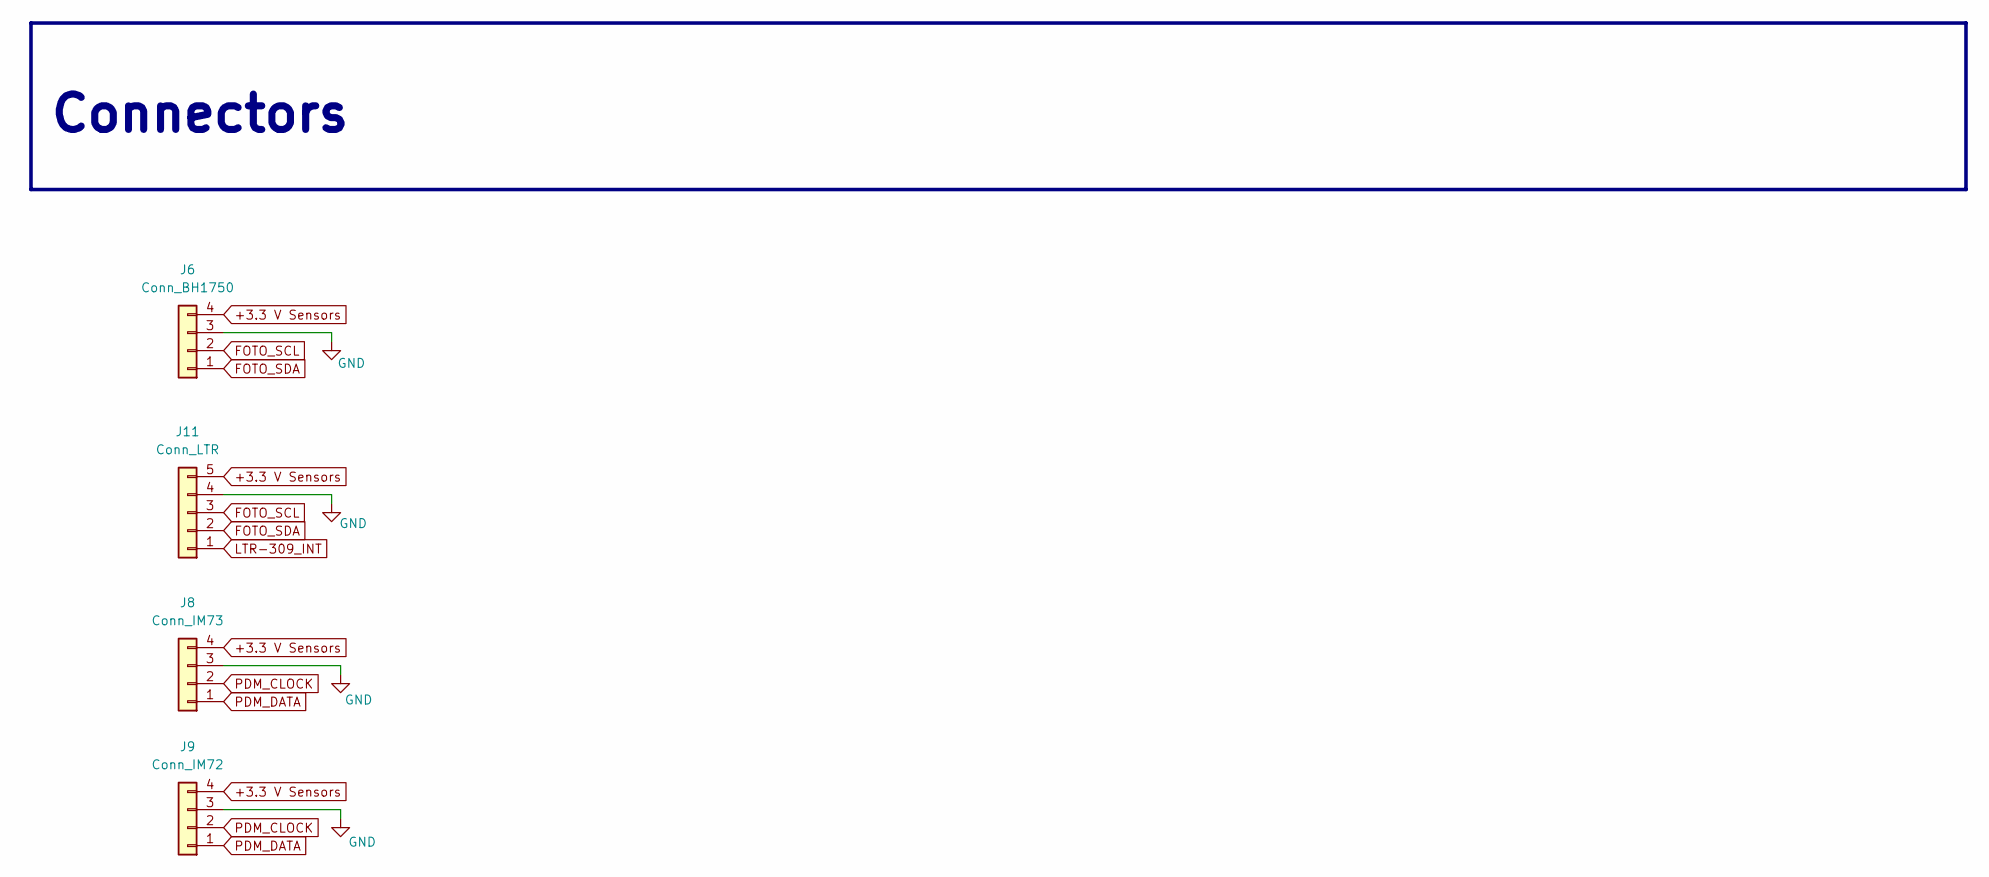
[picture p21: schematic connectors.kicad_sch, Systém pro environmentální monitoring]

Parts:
J6: Conn_BH1750; JST_GH_SM04B-GHS-TB_1x04-1MP_P1.25mm_Horizontal
J8: Conn_IM73; JST_GH_SM04B-GHS-TB_1x04-1MP_P1.25mm_Horizontal
J9: Conn_IM72; JST_GH_SM04B-GHS-TB_1x04-1MP_P1.25mm_Horizontal
J11: Conn_LTR; JST_GH_SM05B-GHS-TB_1x05-1MP_P1.25mm_Horizontal

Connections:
+3.3 V Sensors: J6.4, J8.4, J9.4, J11.5; also elsewhere on the board
FOTO_SCL: J6.2, J11.3; also elsewhere on the board
FOTO_SDA: J6.1, J11.2; also elsewhere on the board
GND: J6.3, J8.3, J9.3, J11.4; also elsewhere on the board
LTR-309_INT: J11.1; also elsewhere on the board
PDM_CLOCK: J8.2, J9.2; also elsewhere on the board
PDM_DATA: J8.1, J9.1; also elsewhere on the board

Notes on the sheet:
Connectors

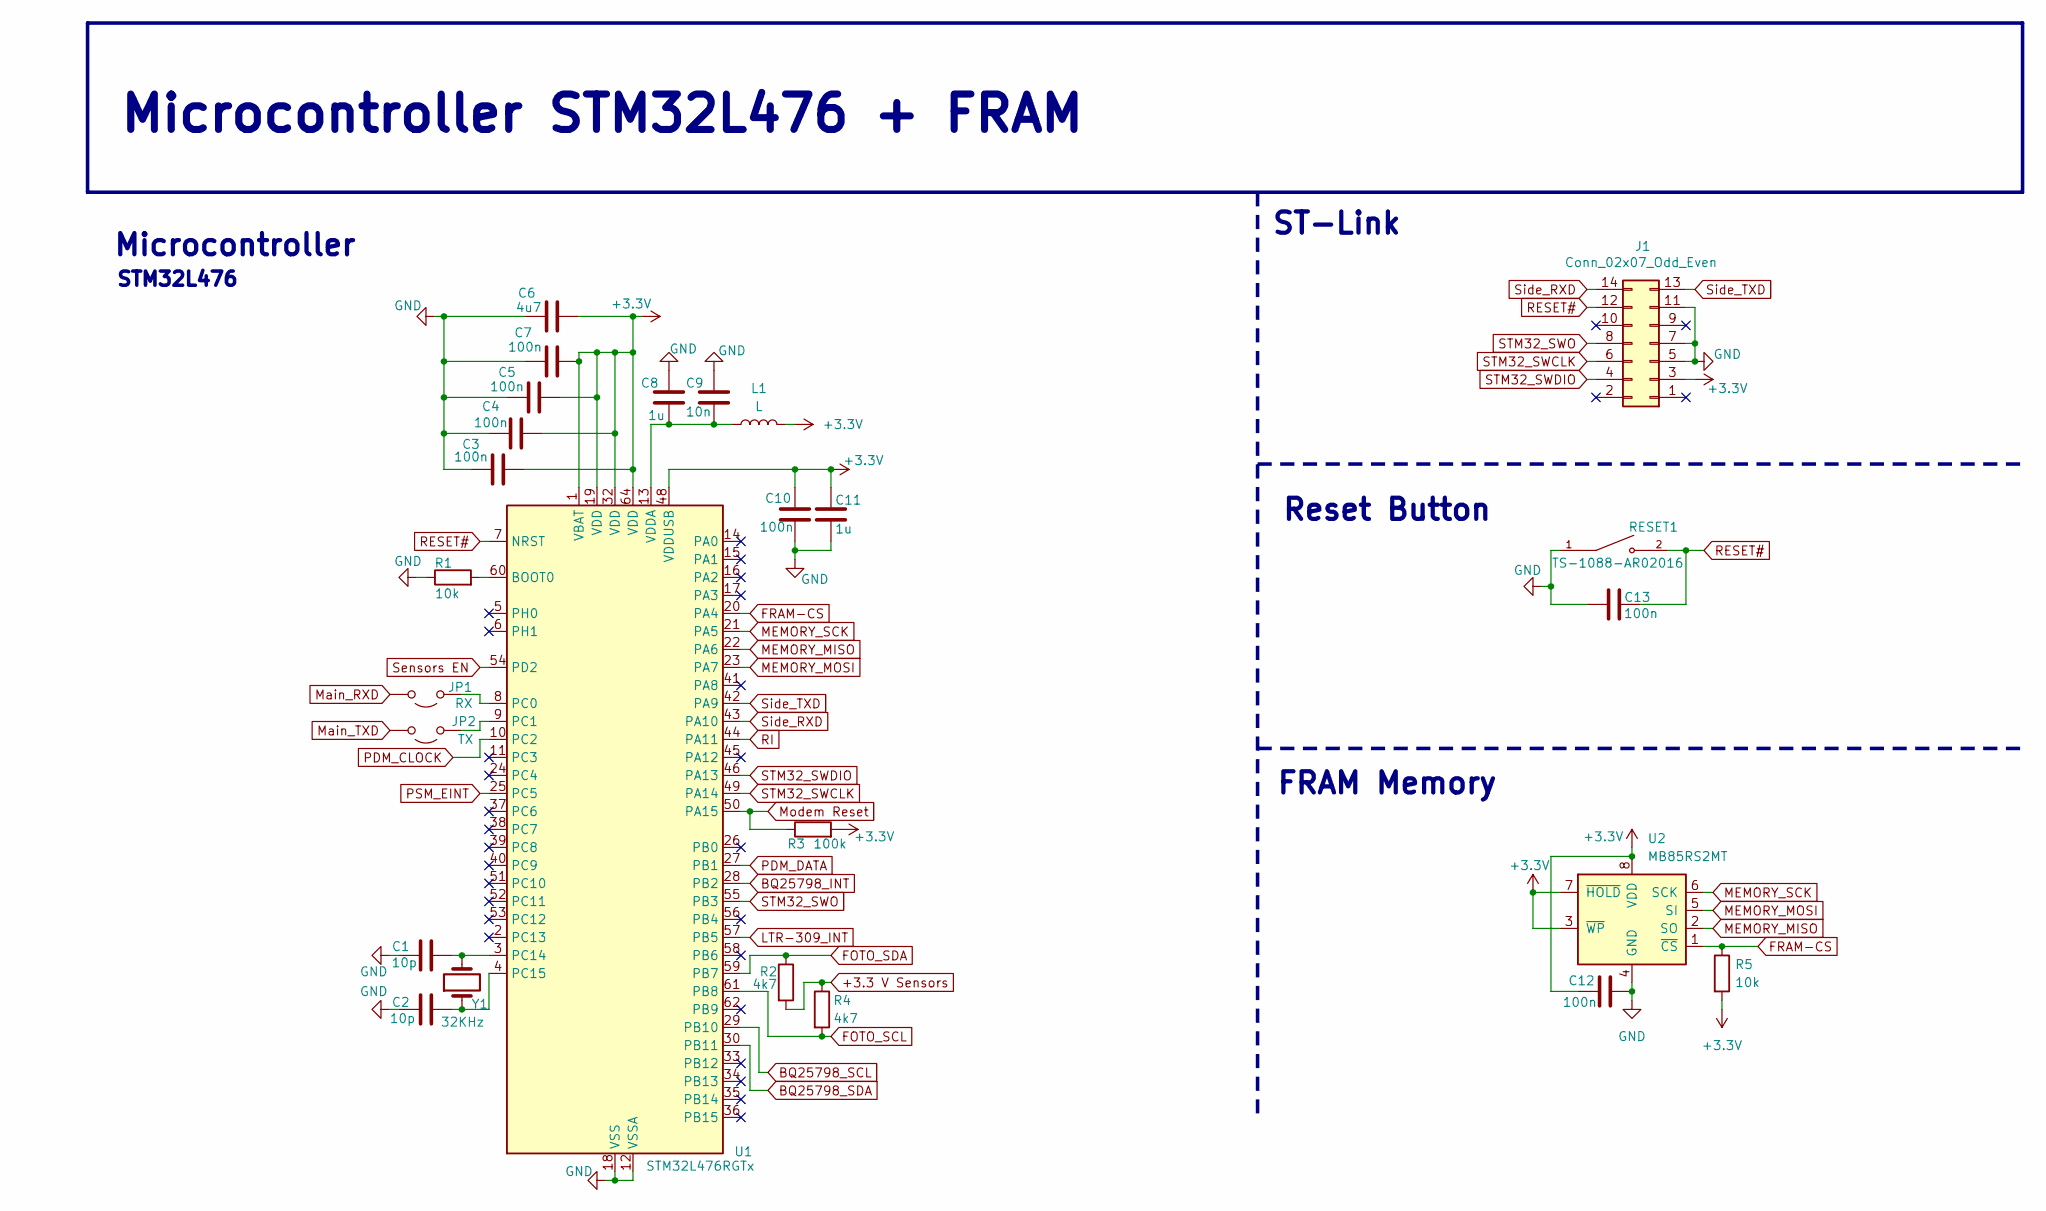
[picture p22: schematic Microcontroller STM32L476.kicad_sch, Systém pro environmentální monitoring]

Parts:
C1, C2: 10p; C_0603_1608Metric_Pad1.08x0.95mm_HandSolder
C3, C4, C5, C7, C10, C12, C13: 100n; C_0603_1608Metric_Pad1.08x0.95mm_HandSolder
C6: 4u7; C_0603_1608Metric_Pad1.08x0.95mm_HandSolder
C8, C11: 1u; C_0603_1608Metric_Pad1.08x0.95mm_HandSolder
C9: 10n; C_0603_1608Metric_Pad1.08x0.95mm_HandSolder
J1: Conn_02x07_Odd_Even; PinHeader_2x07_P1.27mm_Vertical
JP1: RX; PinHeader_1x02_P1.27mm_Vertical; LCSC C225477
JP2: TX; PinHeader_1x02_P1.27mm_Vertical; LCSC C225477
L1: L; L_0603_1608Metric_Pad1.05x0.95mm_HandSolder
R1, R5: 10k; R_0603_1608Metric_Pad0.98x0.95mm_HandSolder
R2, R4: 4k7; R_0603_1608Metric_Pad0.98x0.95mm_HandSolder
R3: 100k; R_0603_1608Metric_Pad0.98x0.95mm_HandSolder
RESET1: TS-1088-AR02016; SW_SPST_TS-1088-xR020; PARTREV N/A; LCSC C720477
U1: STM32L476RGTx; LQFP-64_10x10mm_P0.5mm
U2: MB85RS2MT; SOIC-8_3.9x4.9mm_P1.27mm
Y1: 32KHz; Crystal_SMD_3215-2Pin_3.2x1.5mm

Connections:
+3.3 V Sensors: R2.2, R4.1; also elsewhere on the board
+3.3V: C3.2, C4.2, C5.2, C6.2, C7.2, C10.1, C11.1, C12.1, J1.3, L1.2, R3.2, R5.2, U1.1 (VBAT), U1.19 (VDD), U1.32 (VDD), U1.48 (VDDUSB), U1.64 (VDD), U2.3 (~WP), U2.7 (~HOLD), U2.8 (VDD); also elsewhere on the board
BQ25798_INT: U1.28 (PB2), U1.29 (PB10); also elsewhere on the board
BQ25798_SDA: U1.30 (PB11); also elsewhere on the board
FOTO_SCL: R4.2, U1.61 (PB8); also elsewhere on the board
FOTO_SDA: R2.1, U1.59 (PB7); also elsewhere on the board
FRAM-CS: R5.1, U1.20 (PA4), U2.1 (~CS)
GND: C1.1, C2.1, C3.1, C4.1, C5.1, C6.1, C7.1, C8.1, C9.1, C10.2, C11.2, C12.2, C13.1, J1.5, J1.7, J1.11, R1.1, RESET1.1, U1.12 (VSSA), U1.18 (VSS), U1.31 (VSS), U1.47 (VSS), U1.63 (VSS), U2.4 (GND); also elsewhere on the board
LTR-309_INT: U1.57 (PB5); also elsewhere on the board
MEMORY_MISO: U1.22 (PA6), U2.2 (SO)
MEMORY_MOSI: U1.23 (PA7), U2.5 (SI)
MEMORY_SCK: U1.21 (PA5), U2.6 (SCK)
Main_RXD: JP1.2 (B); also elsewhere on the board
Main_TXD: JP2.2 (B); also elsewhere on the board
Modem Reset: R3.1, U1.50 (PA15); also elsewhere on the board
unnamed: JP1.1 (A), U1.8 (PC0)
unnamed: JP2.1 (A), U1.9 (PC1)
unnamed: R1.2, U1.60 (BOOT0)
unnamed: C1.2, U1.3 (PC14), Y1.2
unnamed: C2.2, U1.4 (PC15), Y1.1
unnamed: C8.2, C9.2, L1.1, U1.13 (VDDA)
PDM_CLOCK: U1.10 (PC2); also elsewhere on the board
PDM_DATA: U1.27 (PB1); also elsewhere on the board
PSM_EINT: U1.25 (PC5); also elsewhere on the board
RESET#: C13.2, J1.12, RESET1.2, U1.7 (NRST)
RI: U1.44 (PA11); also elsewhere on the board
STM32_SWCLK: J1.6, U1.49 (PA14)
STM32_SWDIO: J1.4, U1.46 (PA13)
STM32_SWO: J1.8, U1.55 (PB3)
Sensors EN: U1.54 (PD2); also elsewhere on the board
Side_RXD: J1.14, U1.43 (PA10)
Side_TXD: J1.13, U1.42 (PA9)

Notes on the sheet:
Microcontroller
STM32L476
ST-Link
Reset Button
FRAM Memory
Microcontroller STM32L476 + FRAM

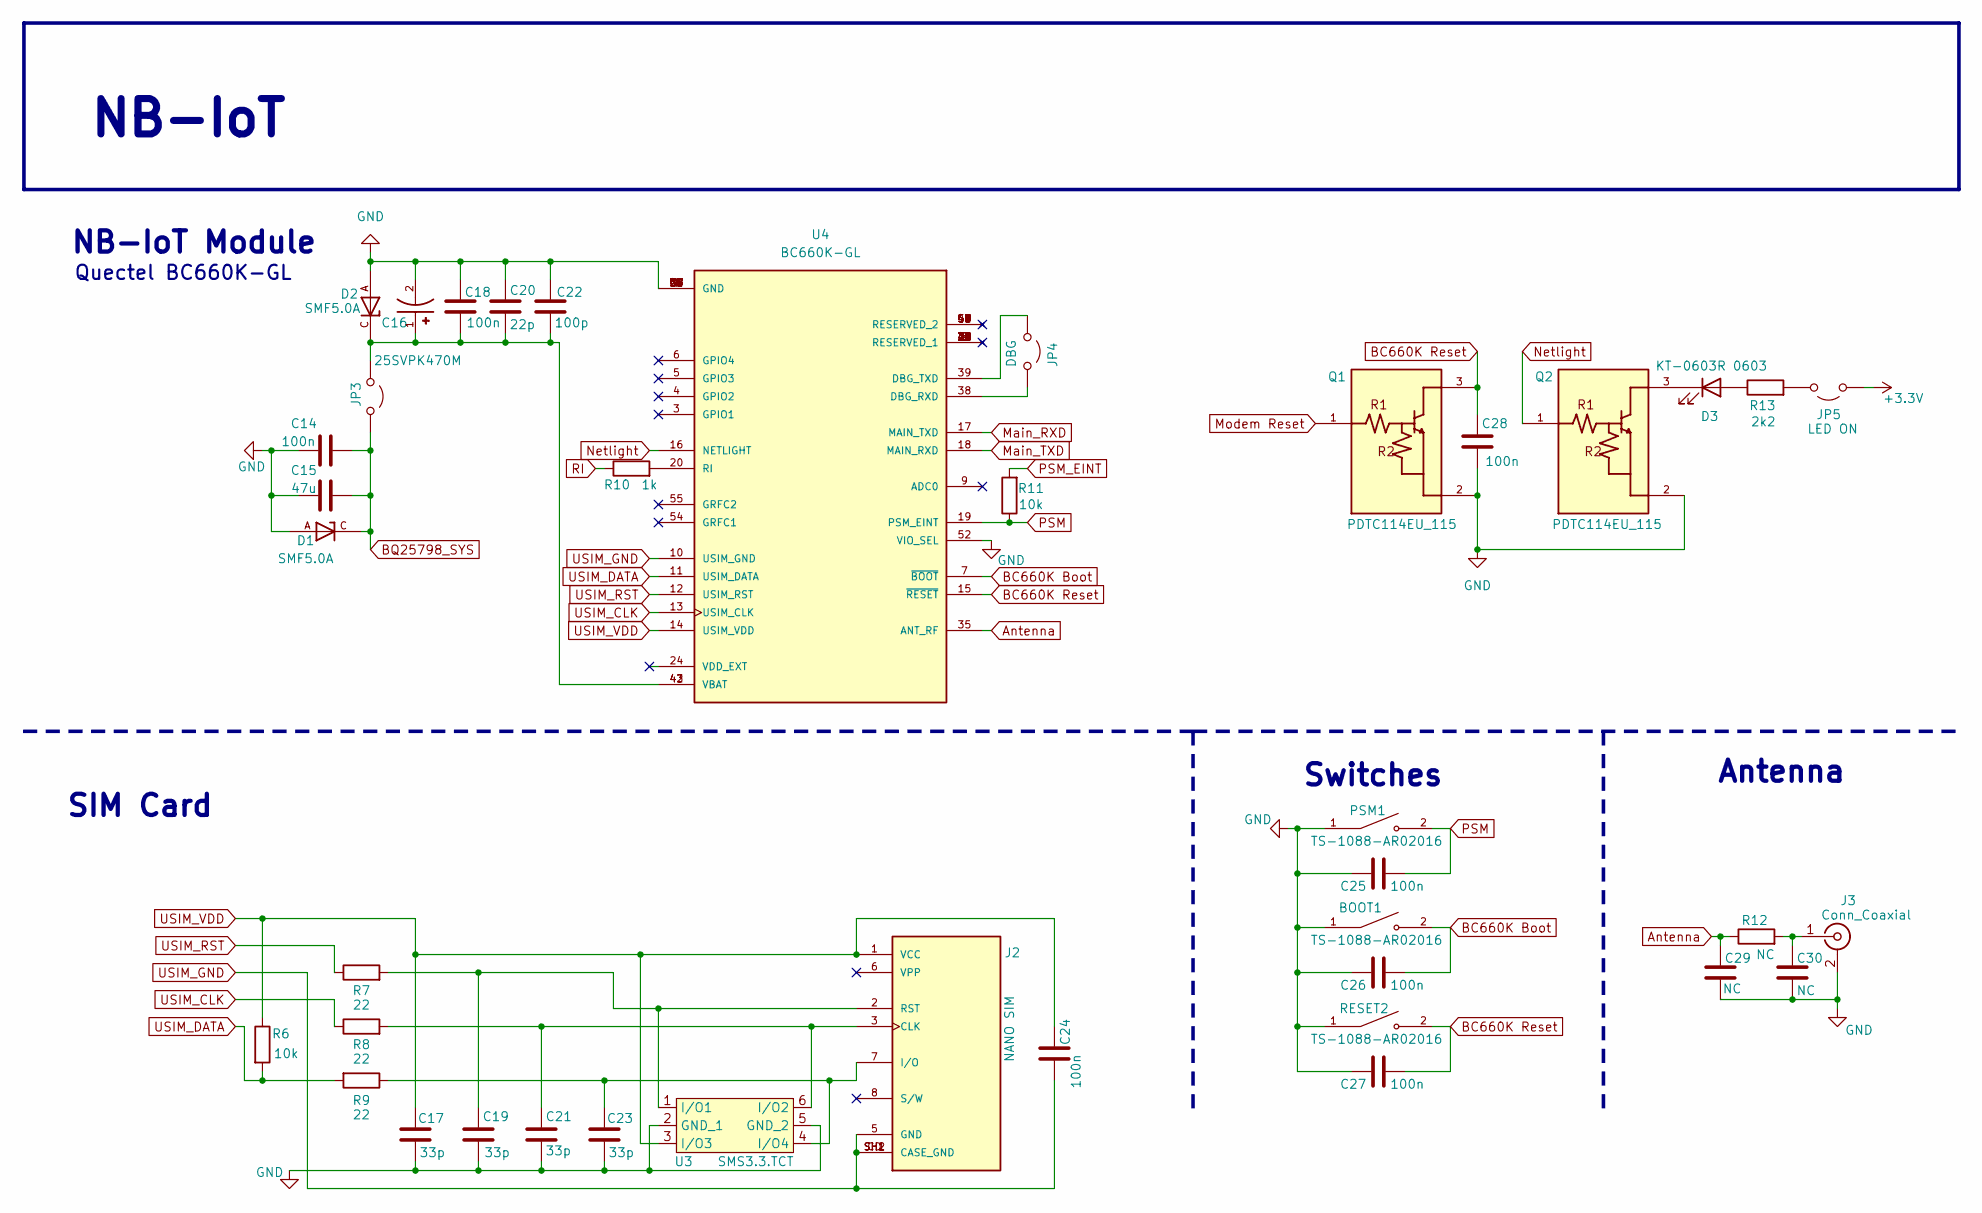
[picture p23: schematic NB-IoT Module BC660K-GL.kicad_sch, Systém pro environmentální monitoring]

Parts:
BOOT1: TS-1088-AR02016; SW_TS-1088-AR02016; PARTREV N/A
C14, C18: 100n; C_0603_1608Metric_Pad1.08x0.95mm_HandSolder
C15: 47u; C_0805_2012Metric_Pad1.18x1.45mm_HandSolder
C16: 25SVPK470M; CAP_25SVPK470M; PARTREV 28-Jun-19; LCSC C454276
C17, C19, C21, C23: 33p; C_0603_1608Metric_Pad1.08x0.95mm_HandSolder; LCSC C1663
C20: 22p; C_0603_1608Metric_Pad1.08x0.95mm_HandSolder
C22: 100p; C_0603_1608Metric_Pad1.08x0.95mm_HandSolder
C24, C25, C26, C27, C28: 100n; C_0603_1608Metric_Pad1.08x0.95mm_HandSolder; LCSC C14663
C29, C30: NC; C_0603_1608Metric_Pad1.08x0.95mm_HandSolder
D1, D2: SMF5.0A; SODFL3718X102N; PARTREV D2103
D3: KT-0603R 0603; LED_0603_1608Metric; LCSC C2286
J2: NANO SIM; nanoSIM_Hinged_CUI_NSIM-2-C; PARTREV 1.0; LCSC C77877
J3: Conn_Coaxial; U.FL_Molex_MCRF_73412-0110_Vertical
JP3: +3.3V; PinHeader_1x02_P2.54mm_Vertical; LCSC C225477
JP4: DBG; PinHeader_1x02_P2.54mm_Vertical; LCSC C225477
JP5: LED ON; PinHeader_1x02_P1.27mm_Vertical; LCSC C706997
PSM1: TS-1088-AR02016; SW_TS-1088-AR02016; PARTREV N/A
Q1, Q2: PDTC114EU_115; SOT65P210X110-3N; PARTREV 12; LCSC C135830
R6, R11: 10k; R_0603_1608Metric_Pad0.98x0.95mm_HandSolder
R7, R8, R9: 22; R_0603_1608Metric_Pad0.98x0.95mm_HandSolder; LCSC C23345
R10: 1k; R_0603_1608Metric_Pad0.98x0.95mm_HandSolder
R12: NC; R_0603_1608Metric_Pad0.98x0.95mm_HandSolder
R13: 2k2; R_0603_1608Metric_Pad0.98x0.95mm_HandSolder; LCSC C4190
RESET2: TS-1088-AR02016; SW_TS-1088-AR02016; PARTREV N/A
U3: SMS3.3.TCT; SOT-23-6; LCSC C780132
U4: BC660K-GL; XCVR_BC660K-GL; PARTREV 1.2

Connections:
+3.3V: JP5.1 (A); also elsewhere on the board
Antenna: C29.1, R12.1, U4.35 (ANT_RF)
BC660K Boot: BOOT1.2, C26.1, U4.7 (~BOOT)
BC660K Reset: C27.1, C28.1, Q1.3, RESET2.2, U4.15 (~RESET)
BQ25798_SYS: C14.2, C15.2, D1.C, JP3.2 (B); also elsewhere on the board
GND: BOOT1.1, C14.1, C15.1, C16.2, C17.1, C18.1, C19.2, C20.1, C21.1, C22.1, C23.2, C25.2, C26.2, C27.2, C28.2, C29.2, C30.2, D1.A, D2.A, J3.2 (Ext), PSM1.1, Q1.2, Q2.2, RESET2.1, U3.2 (GND_1), U3.5 (GND_2), U4.1 (GND), U4.27 (GND), U4.34 (GND), U4.36 (GND), U4.37 (GND), U4.40 (GND), U4.41 (GND), U4.52 (VIO_SEL), U4.56 (GND), U4.57 (GND), U4.58 (GND); also elsewhere on the board
Main_RXD: U4.17 (MAIN_TXD); also elsewhere on the board
Main_TXD: U4.18 (MAIN_RXD); also elsewhere on the board
Modem Reset: Q1.1; also elsewhere on the board
unnamed: D3.2 (A), R13.1
unnamed: D3.1 (K), Q2.3
unnamed: C21.2, J2.3 (CLK), R8.2, U3.6 (I/O2)
unnamed: C23.1, J2.7 (I/O), R9.1, U3.4 (I/O4)
unnamed: C19.1, J2.2 (RST), R7.2, U3.1 (I/O1)
unnamed: C30.1, J3.1 (In), R12.2
unnamed: C16.1, C18.2, C20.2, C22.2, D2.C, JP3.1 (A), U4.42 (VBAT), U4.43 (VBAT)
unnamed: JP4.1 (A), U4.39 (DBG_TXD)
unnamed: JP4.2 (B), U4.38 (DBG_RXD)
unnamed: JP5.2 (B), R13.2
unnamed: R10.2, U4.20 (RI)
Netlight: Q2.1, U4.16 (NETLIGHT)
PSM: C25.1, PSM1.2, R11.1, U4.19 (PSM_EINT)
PSM_EINT: R11.2; also elsewhere on the board
RI: R10.1; also elsewhere on the board
USIM_CLK: R8.1, U4.13 (USIM_CLK)
USIM_DATA: R6.2, R9.2, U4.11 (USIM_DATA)
USIM_GND: C24.2, J2.5 (GND), J2.CD (CASE_GND), J2.SH1 (CASE_GND), J2.SH2 (CASE_GND), U4.10 (USIM_GND)
USIM_RST: R7.1, U4.12 (USIM_RST)
USIM_VDD: C17.2, C24.1, J2.1 (VCC), R6.1, U3.3 (I/O3), U4.14 (USIM_VDD)

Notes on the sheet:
NB-IoT Module
SIM Card
Quectel BC660K-GL
NB-IoT
Antenna
Switches

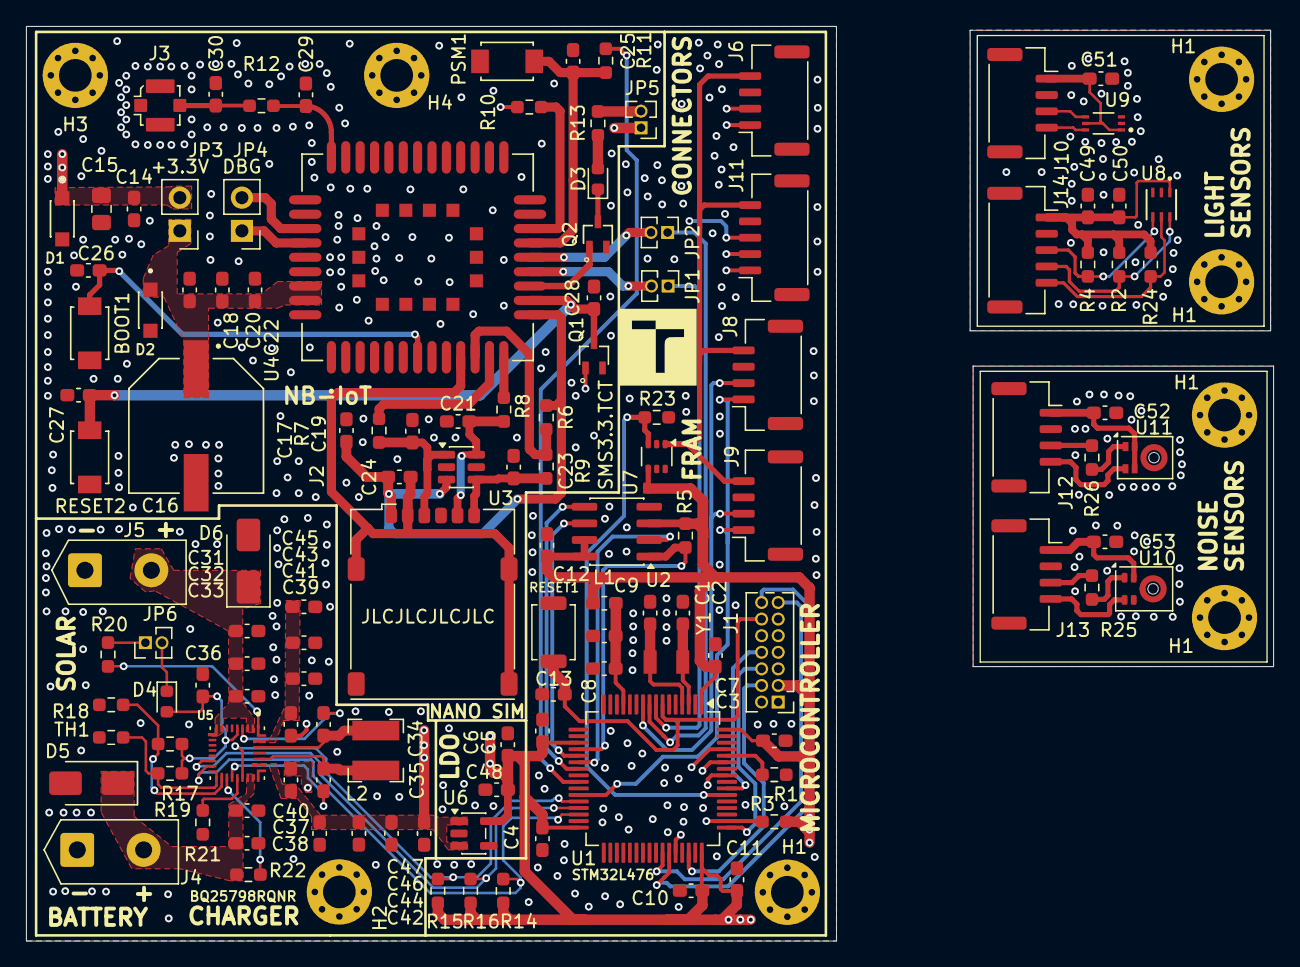
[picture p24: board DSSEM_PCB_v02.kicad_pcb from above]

Board: 4 copper layers, 62.0 x 70.0 mm, 133 parts (0 on the bottom side), 72 nets.

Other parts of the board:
H1, H1#2, H1#3, H1#4, H1#5, H2, H3, H4: MountingHole_2.5mm_Pad_Via

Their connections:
GND: H1#5.1, H2.1, H3.1, H4.1; also elsewhere on the board

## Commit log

2026-04-06 /hardware update
    [connectors.kicad_sch]
2026-04-06 Source files for /hardware
    [DSSEM_PCB_v02.kicad_pcb, DSSEM_PCB_v02.kicad_sch, Microcontroller STM32L476.kicad_sch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]
